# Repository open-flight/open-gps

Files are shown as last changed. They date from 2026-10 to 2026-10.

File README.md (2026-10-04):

# open-gps: Golf Shot Tracker

A handheld, open-source golf shot tracker built from SparkFun Qwiic parts. Turn the dial to pick a club, click at the ball, walk to where it landed, click again, and it shows the distance in yards. Every shot is saved to flash and can be exported over USB as GeoJSON or CSV, with start and landing coordinates for each shot.

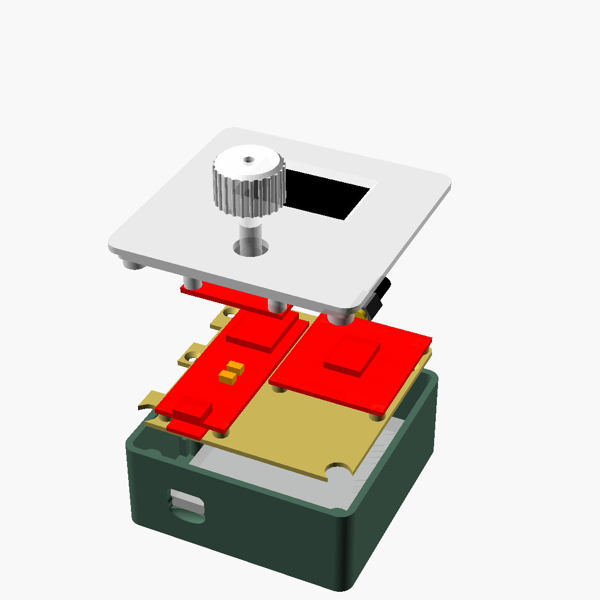
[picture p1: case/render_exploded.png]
Exploded view of the enclosure


> [!TIP]
> **🛒 [Get every part in one click: SparkFun wishlist](https://www.sparkfun.com/wishlist/shared/index/code/GlRlCXNElCsNx5QNRKp5i46RxsmUJz3x/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)**: all the electronics on one list, ready to add to your cart.
> <sub>This is a referral link, so buying through it supports the project at no extra cost to you. Prefer not to use it? Every part is listed in [Hardware](#hardware).</sub>

- **Firmware:** Arduino (ESP32-S3). A single-dial UI on a 128×64 OLED. Rounds survive resets and power loss.
- **Enclosure:** parametric OpenSCAD. It prints in PETG without supports and comes to 74.4 × 74.4 × 31.6 mm.
- **Host simulation:** the real firmware state machine runs on your computer against stubbed hardware, so most changes can be tested without the device.

| Path | What's there | More detail |
|---|---|---|
| `firmware/shot_tracker/` | Arduino sketch (`app.cpp` plus headers) | [firmware/README.md](firmware/README.md) |
| `firmware/test/` | Host simulation (`make -C firmware/test`) | [firmware/README.md](firmware/README.md) |
| `case/cad/shot_tracker_case.scad` | Enclosure source (single file, all parameters at the top) | [case/README.md](case/README.md) |
| `case/stl/` | Pre-exported printable parts | [case/README.md](case/README.md) |
| `tools/noop-ctags/` | Build workaround for Apple Silicon Macs without Rosetta | [Step 2](#2-build-the-firmware) |

---

## Hardware

> [!TIP]
> **[Add all the electronics to your cart from the SparkFun wishlist →](https://www.sparkfun.com/wishlist/shared/index/code/GlRlCXNElCsNx5QNRKp5i46RxsmUJz3x/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)**
> It covers the board, GPS, antenna, OLED, Twist, battery and Qwiic cables. You still need the screws, heat-set inserts and slide switch from [case/README.md](case/README.md#hardware). <sub>(Referral link.)</sub>

| Qty | Part | Notes |
|---|---|---|
| 1 | SparkFun Thing Plus ESP32-S3 | Main board: USB-C, LiPo charger, MAX17048 fuel gauge, one Qwiic port |
| 1 | SparkFun GPS Breakout NEO-M9N, SMA (Qwiic) | Edge-mount SMA jack |
| 1 | GPS/GNSS Magnetic Mount Antenna, 3 m (SMA) | Active antenna. The breakout powers it. |
| 1 | SparkFun Qwiic OLED 1.3" 128×64 | Monochrome |
| 1 | SparkFun Qwiic Twist RGB rotary encoder | The only control (turn, click, hold) |
| 1 | Lithium Ion Battery 2 Ah, JST-PH (SparkFun PRT-13855) | Measure yours. See [case/README.md](case/README.md#measure-before-you-print) |
| 1 | SparkFun Qwiic Cable Kit | |
| — | Screws, heat-set inserts, slide switch | Full list in [case/README.md](case/README.md#hardware) |

All parts share one I2C bus and the default addresses don't clash, so **no jumpers or address changes are needed**:

| Device | I2C address |
|---|---|
| MAX17048 fuel gauge (on the Thing Plus) | 0x36 |
| Qwiic OLED 1.3" | 0x3D |
| Qwiic Twist | 0x3F |
| NEO-M9N GPS | 0x42 |

---

## Quick start

These steps take you from a fresh clone to a flashed, working device. They're written so an agent can run them in order. Each step ends with a **Verify** check, so confirm it before moving on.

Requirements: macOS, Linux or Windows (WSL works for building, but flashing needs USB access); a USB-C **data** cable; and about 1.5 GB of disk space for the ESP32 toolchain.

### 0. Wire the parts (bench test before the case)

Don't have the parts yet? Use the [SparkFun wishlist](https://www.sparkfun.com/wishlist/shared/index/code/GlRlCXNElCsNx5QNRKp5i46RxsmUJz3x/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).

Daisy-chain the Qwiic cables. Electrically the order doesn't matter, because it's one bus:

```
Thing Plus ─ OLED ─ Twist ─ GPS
```

Inside the case, the GPS port facing the top wall has no room for a plug, so put the GPS **at the end of the chain**, using its bottom-facing port.

1. Screw the antenna onto the GPS SMA jack.
2. Optionally, plug the battery into the Thing Plus JST connector. USB power alone is enough for a bench test.
3. Plug the Thing Plus into the computer over USB-C.

### 1. Install the toolchain

Install `arduino-cli`:

| OS | Command |
|---|---|
| macOS | `brew install arduino-cli` |
| Linux | `curl -fsSL https://raw.githubusercontent.com/arduino/arduino-cli/master/install.sh \| sh` (installs to `./bin`; add it to `PATH`) |
| Windows | `winget install ArduinoSA.CLI` |

Then add the ESP32 core and the four libraries:

```bash
arduino-cli config init --overwrite   # only if you have no arduino-cli config yet; otherwise skip
arduino-cli config add board_manager.additional_urls https://espressif.github.io/arduino-esp32/package_esp32_index.json
arduino-cli core update-index
arduino-cli core install esp32:esp32
arduino-cli lib install "SparkFun u-blox GNSS v3" "SparkFun Qwiic OLED Arduino Library" \
  "SparkFun Qwiic Twist Arduino Library" "SparkFun MAX1704x Fuel Gauge Arduino Library"
```

**Verify:**

```bash
arduino-cli board listall | grep -i "ESP32-S3 Thing Plus"
# expected: SparkFun ESP32-S3 Thing Plus   esp32:esp32:sparkfun_esp32s3_thing_plus
arduino-cli lib list | grep -i sparkfun   # expect all four libraries
```

These versions are known to work: ESP32 core 3.3.12, u-blox GNSS v3 3.1.15, Qwiic OLED 1.0.15, Qwiic Twist 1.0.4 and MAX1704x 1.0.4.

### 2. Build the firmware

Run every command from the repository root. The board ID and options are:

```bash
FQBN="esp32:esp32:sparkfun_esp32s3_thing_plus:CDCOnBoot=cdc,PartitionScheme=default"
```

- `CDCOnBoot=cdc` is **required**. Without it, serial over the USB-C port is silent.
- `PartitionScheme=default` (4 MB flash, 1.5 MB SPIFFS) is where saved rounds live. Changing it **erases all rounds**.

```bash
arduino-cli compile -b "$FQBN" firmware/shot_tracker
```

**Apple Silicon Mac without Rosetta 2:** the build fails with `ctags: bad CPU type in executable`. That's because Arduino's `ctags` helper is Intel-only. You can either:

- install Rosetta with `softwareupdate --install-rosetta --agree-to-license`, or
- point the build at the stand-in `ctags` in this repo, which needs no system changes. It's safe because `shot_tracker.ino` has no functions, so `ctags` has nothing to do.

  ```bash
  arduino-cli compile -b "$FQBN" --build-property "tools.ctags.path=$PWD/tools/noop-ctags" firmware/shot_tracker
  ```

  Add the same `--build-property` to every compile and upload command below.

**Verify:** the output ends with `Sketch uses ~440000 bytes (33%) of program storage space`.

### 3. Find the port and flash

```bash
arduino-cli board list
```

| OS | Port looks like |
|---|---|
| macOS | `/dev/cu.usbmodem101` |
| Linux | `/dev/ttyACM0` (your user must be in the `dialout` group) |
| Windows | `COM3` |

```bash
PORT=/dev/cu.usbmodem101   # use the port from `board list`
arduino-cli compile --upload -p "$PORT" -b "$FQBN" firmware/shot_tracker
```

**Verify:** the output ends with `Hash of data verified.` and `Hard resetting via RTS pin...`

If no port appears or the upload fails:
1. Check that the EN slide switch is ON, if it's already wired.
2. Try a different USB-C cable. Charge-only cables don't show up as a port.
3. Put the board in upload mode by hand: **hold BOOT, tap RESET, release BOOT**, then upload again.
4. Press RESET afterwards to start the new firmware.

### 4. Check the hardware over serial

```bash
arduino-cli monitor -p "$PORT" -c baudrate=115200
```

Opening the monitor usually resets the board. If it doesn't, press RESET. You should see:

```
oled=1 twist=1 gps=1 fuel=1 fs=1
```

A `0` means that part wasn't found, so reseat its Qwiic cable. `fs=0` means the storage partition is missing; recheck `PartitionScheme=default`. The first boot formats storage, which leaves the screen blank for a few seconds. That's normal.

Type `gps` and press Enter:

```
present=1 fix=3 ok=1 siv=14 lat=... lon=... acc=1.20m unix=...
```

You want `fix=3` and `ok=1`. Indoors you'll usually see `fix=0 siv=0`. See [GPS won't get a fix](#gps-wont-get-a-fix).

For an agent without an interactive terminal, this sends commands and captures 8 seconds of output:

```bash
( (sleep 2; printf 'gps\nls\n'; sleep 5) | arduino-cli monitor -p "$PORT" -c baudrate=115200 --quiet > serial.log 2>&1 & P=$!; sleep 8; kill $P ); cat serial.log
```

### 5. Run the host simulation (no hardware needed)

```bash
make -C firmware/test
```

It needs `g++` or `clang++` (C++17). It plays a scripted round (drives, putts, hole-out, cancel, undo, a RESET mid-shot, a no-fix save, finishing, deleting a round, exporting and power-off), and it flags any text or graphics drawn off the 128×64 screen.

**Verify:** the last line is `0 failures`. AddressSanitizer hangs at startup on recent macOS, so on macOS the Makefile uses UBSan only. Linux uses both.

### 6. Print and assemble the case

The STLs in `case/stl/` are ready to print in PETG with no supports. Print orientation, slicer settings, the hardware list and the 8-step assembly order are all in **[case/README.md](case/README.md)**.

**Flash before you close the case.** Once the lid is on, the BOOT button is under the Twist.

To change the enclosure, edit the parameters at the top of `case/cad/shot_tracker_case.scad` and re-export:

```bash
# OpenSCAD 2021.01 is Intel-only on macOS; use the snapshot build (native on Apple Silicon):
brew install --cask openscad@snapshot        # macOS; Linux: your distro's openscad, or the AppImage
cd case
for p in shell lid plate knob plunger; do
  openscad --backend=manifold -D "part=\"$p\"" -o stl/$p.stl cad/shot_tracker_case.scad
done
```

Collision checks: each of these should print `Current top level object is empty`, or produce a zero-volume STL where parts only touch:

```bash
for c in chk_shell chk_lid chk_plate chk_shell_plate chk_shell_lid chk_lid_plate chk_plunger chk_plunger_lid; do
  echo "== $c"; openscad --backend=manifold -D "part=\"$c\"" -o /tmp/$c.stl cad/shot_tracker_case.scad 2>&1 | grep -E "empty|ERROR"
done
```

---

## Using it

There's one control, the dial: **turn** to choose, **click** to select or mark, and **hold** (0.7 s) for the menu.

1. **New round** starts on hole 1.
2. Turn to a club, then **click at the ball**. The device averages GPS for 2.5 s, so hold still.
3. Walk to the ball. The screen shows the live distance from where you hit.
4. **Click at the ball** again. The shot distance is shown in large digits and saved.
5. **Putter:** one click records the putt; there's no landing step.
6. **Hole out:** turn one step past Putter (the flag icon) and click.
7. **Saved rounds** on the home screen lists rounds, and you can delete one from there.

The header shows the hole and shot, a GPS pin with the satellite count (the pin blinks while searching), and a battery gauge with a bolt while charging. The dial's LED colour shows the state. The full controls, menu, LED colours and storage behaviour are in [firmware/README.md](firmware/README.md).

**Reset on the course:** press the RESET plunger on the lid, between the screen and the dial, or switch the EN slide switch off and on. The round resumes on the same hole and shot.

### Exporting rounds (USB serial, 115200 baud)

| Command | Output |
|---|---|
| `help` | Command list |
| `ls` | Rounds: id, shots, done/active, start time |
| `geojson <id>` | GeoJSON. Each shot is a start→landing line and each putt is a point. |
| `csv <id>` | CSV, one row per shot |
| `rm <id>` | Delete a round |
| `gps` | Current fix |

For a quick look, paste the `geojson` output into [geojson.io](https://geojson.io) and switch the base layer to satellite.

---

## Configuration

Firmware settings are in `firmware/shot_tracker/config.h`:

| Setting | Default | What it does |
|---|---|---|
| `CLUBS[]` | Driver … LW, Putter | The dial order. Names are up to 14 characters. The putter must match `PUTTER_NAME`. |
| `USE_YARDS` | `true` | `false` switches to metres |
| `GPS_MARK_WINDOW_MS` | 2500 | How long a mark averages GPS fixes |
| `GPS_MAX_GOOD_HACC_MM` | 8000 | Fixes less accurate than this are ignored while marking |
| `LONG_PRESS_MS` | 700 | How long to hold for the menu |
| `RESULT_SHOW_MS` | 4000 | How long the shot distance stays on screen |

Enclosure settings are at the top of `case/cad/shot_tracker_case.scad`. The ones you're most likely to change:
- `batt`: the battery pocket, currently 55 × 64 × 6.4. If you change its length, change `plate_region_h` by the same amount.
- `rst_recess`: how far the RESET plunger stands out from the lid. Negative means it sticks out.
- `sw_*`: the slide switch size.
- The clearances `clr` and `lip_clr`.

---

## Troubleshooting

### GPS won't get a fix
- **Indoors:** `siv=0` or only a few weak satellites is normal. Run the 3 m antenna cable outside or onto a windowsill.
- **Interference:** keep the antenna at least 1 m from the laptop, the ESP32 board and the USB cable. All of them radiate noise near the GPS band.
- **Ground plane:** the magnetic puck works best on a steel surface, such as a baking tray, outdoors.
- **First fix (cold start):** this can take 1–3 minutes under open sky. Later fixes are much faster.
- **Antenna check:** the NEO-M9N reports antenna status over UBX `MON-HW`. `aStatus=2` means OK and `aPower=1` means powered. A short sketch that prints `getHWstatus()` and `getNAVSAT()` from the u-blox library, using signal strength (C/N0) and the jamming indicator, quickly separates antenna, cable and interference problems.

### Build and flash
| Symptom | Fix |
|---|---|
| `ctags: bad CPU type in executable` | Apple Silicon without Rosetta. Use `--build-property tools.ctags.path=$PWD/tools/noop-ctags` (Step 2). |
| No serial output at all | `CDCOnBoot=cdc` is missing from the FQBN |
| No port appears | Use a data cable, turn EN ON, or use BOOT + RESET (Step 3) |
| `fs=0` at boot | Wrong partition scheme. Use `PartitionScheme=default`. |
| `make -C firmware/test` hangs on macOS | Older Makefile using ASan. The current Makefile uses UBSan only on macOS. |

### Saved rounds and reflashing
- Normal uploads **keep** saved rounds; they live in a separate flash partition.
- These **erase all rounds**, so export first:
  - *Erase All Flash Before Sketch Upload*
  - changing the partition scheme
  - `esptool erase_flash`
- Bumping `ROUND_VERSION` in `model.h` makes older rounds unreadable.

---

## Power notes

- **Power off** (in the menu) saves the round, cuts the Qwiic rail (GPIO45) and deep-sleeps. Press RESET to wake it.
- The **EN slide switch** is the hard off. The battery still charges over USB while it's off.
- Recommended board mods (cut-trace jumpers on the Thing Plus):
  - **JP2:** the Qwiic rail's default pull-up. Cutting it stops about 330 µA of drain while the device is off.
  - **JP1:** the power LED. Cutting it saves about 1 mA while running.
- Charging runs at about 213 mA, so a full 2 Ah charge takes around 10 hours.

---

## Roadmap (not in v0.1)

- Penalty strokes and provisional balls
- Choosing which clubs to carry
- Pin and green positions, and a course-overlay viewer (the GeoJSON properties are designed for this)
- Auto sleep between holes
- BLE sync to a phone
- An internal patch antenna, and a belt or cart clip

## Contributing

1. Run `make -C firmware/test` before and after firmware changes; it must end in `0 failures`. Add a check to `firmware/test/sim.cpp` for new behaviour.
2. For case changes, run the collision checks in Step 6, re-export the affected STLs, and update `case/README.md` if dimensions or assembly change.
3. Keep screen text and graphics within 128×64. The simulation flags anything that runs off the screen.

## License

Copyright (C) 2026 Coleman Rollins and open-gps contributors.

open-gps is licensed under the **GNU Affero General Public License v3.0**; see [LICENSE](LICENSE). That covers the firmware, the enclosure CAD and STLs, and the documentation. You can use, modify and share it, but if you distribute a modified version, or run one as a network service, you must release your changes under the same license.

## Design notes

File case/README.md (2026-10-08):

# Golf Shot Tracker – Handheld Enclosure (v0.1)

A parametric OpenSCAD enclosure for the SparkFun plug-and-play shot tracker. It holds these parts:

- SparkFun Thing Plus ESP32-S3
- SparkFun GPS Breakout NEO-M9N, SMA (Qwiic)
- SparkFun Qwiic OLED 1.3" 128x64
- SparkFun Qwiic Twist RGB Rotary Encoder
- Lithium Ion Battery 2Ah
- GPS/GNSS Magnetic Mount Antenna 3m (SMA)
- SparkFun Qwiic Cable Kit

Board outlines, mounting holes and connector positions come from SparkFun's own Eagle and KiCad source files on GitHub. Only the parts listed under "Measure before you print" were estimated.

## Size

The case is 74.4 x 74.4 x 31.6 mm (W x H x D). The GPS antenna plugs into an SMA port in the top wall, and the antenna and its cable stay outside the case.

## Layout

Viewed from the front:

- **Top wall:** the SMA antenna port. This is the GPS board's own edge-mount SMA jack, sitting 0.6 mm behind the wall. An 11 mm opening lets the plug's coupling nut reach the thread. To its left are a zip-tie anchor (to strain-relieve the antenna cable) and a lanyard lug. To its right, a small bulge holds a 5 mm pocket behind the GPS's top-edge Qwiic port, so a plug fits there.
- **Front:** the OLED window with the Twist dial below it, and the **RESET button** between them. A printed plunger, standing 1 mm proud of the lid, presses the Thing Plus RESET button, which wakes the device from firmware power-off.
- **Left side:** the **EN slide switch**, the hard power-off. It pulls the Thing Plus EN pin to GND, which disables the main 3.3 V regulator. Charging still works with it off.
- **Bottom end:** USB-C (charging and programming) and a microSD slot, both on the Thing Plus.
- **Inside, stacked from the back:** the battery sits on the floor. An internal plate sits above it and carries the Thing Plus (left) and the GPS (right, rotated so its SMA faces the top wall).
- **Lid:** the OLED and the Twist screw onto bosses on the lid.
- **Closing:** the lid has two tongues that hook under the top wall. It swings down and is held by two M3 screws from the back.

## Files

- `cad/shot_tracker_case.scad`: single source file. Set `part` to `shell`, `lid`, `plate`, `knob`, `plunger`, `assembly` or `exploded`.
- `stl/`: pre-exported parts in print orientation.

To re-export a part:
```
openscad -D 'part="shell"' -o shell.stl cad/shot_tracker_case.scad
```
Collision-check targets (`chk_shell`, `chk_lid`, `chk_plate`, …) intersect each part with the ghost components. They should come back empty or zero-volume.

## Hardware

| Qty | Item | Where |
|---|---|---|
| 2 | M3 heat-set insert, 4.0 mm hole, ≤5.8 mm long | lid bottom corners |
| 2 | M3 x 25 socket head | back → lid |
| 6 | M2.5 x 5 pan head (self-tapping into PETG) | Thing Plus (2), GPS (4) → plate. **Don't use longer than 5 mm.** A 6 mm screw pokes through the plate toward the battery. |
| 3 | M2.5 x 6 flat head | plate → shell pillars |
| 4 | M2.5 x 8 pan head | Twist → lid |
| 4 | M2.5 x 4 pan head | OLED → lid (longer screws will dimple the lid face) |
| 1 | Mini SPDT slide switch, SS12D00G3-style (8.7 x 3.6 x 3.6 mm body, 3-pin, 2.54 mm pitch) | left wall, wired EN ↔ GND |
| 2 | ~6 cm of 28–30 AWG wire | switch to the Thing Plus EN and GND pins |
| 1 | Small square of 1 mm foam tape | behind the battery (optional anti-rattle) |

## Printing (Bambu X2D, PETG)

- 0.4 mm nozzle, 0.2 mm layers, 3–4 walls, 20% gyroid.
- No supports needed on any part.
- **Shell:** print back-down.
- **Lid:** print face-down. A textured PEI plate gives a nice front finish.
- **Plate:** print flat.
- **Knob:** print upright. Use clear or translucent PETG so the encoder's RGB light shows through the centre light pipe.
- **Plunger:** print upright, tip down. Use 0.12 mm layers for a clean 2.1 mm shaft.

## Assembly order

1. Press the 2 M3 inserts into the lid corner bosses. Drop the RESET plunger into its guide tube from inside the lid. Its collar keeps it from falling out the front.
2. Screw the OLED (face down, glass against the lid) and the Twist (encoder through the round hole) to the lid. Plug in Qwiic cables. OLED → Twist is a short hop.
3. Solder the slide switch: the centre pin to the Thing Plus **EN** pin and one outer pin to **GND**. Slide = off pulls EN low. Hold the switch against the left wall with the actuator through the slot and fix it with hot glue (there's no cradle; the plate has a notch so it drops in past the switch).
4. Put the battery in the shell. The lead exits toward the left side.
5. Screw the Thing Plus and the GPS to the plate, then drop the plate in over the battery. Route the battery lead up through the left notch into the Thing Plus JST. Screw the plate down (3x M2.5 flat head).
6. Connect Qwiic: Thing Plus → GPS → OLED → Twist. Both GPS Qwiic ports are usable. The one facing the top wall plugs into the pocket beside the SMA port.
7. Hook the lid's top tongues under the top wall, swing the bottom down, and fit the 2 M3 x 25 screws from the back.
8. Screw the antenna onto the SMA port. Zip-tie the cable to the anchor next to the port so tugs don't load the GPS board's edge connector.

## Measure before you print

These values were estimated or conflict between sources. Every one is a single parameter at the top of the `.scad` file.

- **`batt`:** SparkFun and DigiKey list 61 x 53.3 x 6.4 mm, but some resellers list 68.8 x 49.2 x 5.6 mm. The default pocket is 55 x 64 (2 mm longer than the listed cell, which measured tight in practice). If yours is the longer cell, it won't fit without reworking the layout.
- **`oled_glass_t`:** glass plus adhesive thickness (default 1.6). This sets the OLED boss height.
- **`enc_body` / `enc_hole_d`:** encoder body 12.4 x 13.4 x 7.8 mm, from a third-party model of COM-15141. The lid hole clears an M9 bushing.
- **`sw_body` / `sw_slot`:** the slide switch body and actuator slot. Measure your switch.
- **`sma_edge_gap` / `sma_port_d`:** the gap between the GPS board edge and the top wall, and the port opening size. If the plug won't thread fully, reduce the gap or enlarge the opening.

## Known limitations / next steps

- **External antenna.** The antenna rides outside the case on its 3 m cable. A small active patch antenna could later go inside the case, or in a snap-on cap over the port.
- **Board mods:** cut JP2 on the Thing Plus so firmware power-off doesn't fight the Qwiic rail's 10k pull-up. Details are in the firmware README.
- **Slow charging.** The Thing Plus charger runs at ~213 mA, so a full 2 Ah charge takes roughly 10 hours. Fine overnight, slow for a top-up.
- **No weather sealing** (per v0.1 scope).
- **No belt or cart clip yet.** The back is flat, so a clip or mount plate can be added later.

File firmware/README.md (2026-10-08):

# Shot Tracker Firmware (v0.1)

Arduino firmware for the SparkFun Thing Plus ESP32-S3 with the NEO-M9N GPS, the Qwiic OLED 1.3" and the Qwiic Twist.

## Controls

There's one control, the dial:

- **Turn** to pick a club or move through menus.
- **Click** to select or to mark a position.
- **Hold** (0.7 s) to open the menu. Holding again closes it.

## Playing a round

1. From the home screen, choose **New round**. The round starts on hole 1.
2. **Pick a club.** Turn the dial and the club name shows on screen.
3. **Click at the ball.** The device averages GPS for 2.5 s ("Hold still"). That marks the start of the shot.
4. **Walk to the ball.** The screen shows the live distance from the start.
5. **Click at the ball again.** The landing point is marked and the shot distance is shown for 4 s.
6. **Putts:** select *Putter* and one click records the shot. There's no landing step. The dial stays on the putter for the next putt.
7. **Finish the hole:** turn one click past *Putter* to **Hole out** and click. That advances to the next hole. Holing out on 18 asks whether to finish the round.

**Dial LED colours**

| Colour | Meaning |
|---|---|
| Green | Ready |
| Blue | Shot in flight |
| White | Marking a position |
| Amber | No GPS fix |
| Purple | In a menu |

**Menu** (hold the dial during a round):

- Back
- Next hole
- Go to hole…
- Cancel this shot / Undo last shot (asks to confirm)
- Scorecard
- GPS status
- End round (asks to confirm)
- Power off

**Saved rounds** (home screen) lists the newest 9 rounds as `#id date shots`; `*` marks a round that was never finished. Click a round to delete it (asks to confirm, defaults to No). Older rounds appear as newer ones are deleted, or remove them over USB with `rm <id>`.

**If there's no GPS fix when you mark:** you get a choice of *Try again*, *Save without GPS* or *Cancel*. Save without GPS keeps the stroke count correct, but that shot has no distance.

## Storage and resume

- **Where rounds live:** in LittleFS on the internal flash. The round is rewritten after every change, using a temp file and a swap, so power loss can't corrupt it.
- **Resume:** a RESET, a dead battery or the EN switch mid-round all come back to the same hole and the same shot. That includes a shot that's still in flight.
- **Capacity:** 250 shots per round. The 1.5 MB partition holds hundreds of rounds.

## Exporting rounds (USB serial, 115200)

| Command | Output |
|---|---|
| `ls` | List rounds (id, shots, done/active) |
| `geojson <id>` | Export as GeoJSON. Each shot is a start→landing line and each putt is a point. Properties include club, distance and accuracy. |
| `csv <id>` | Export as CSV, one row per shot |
| `rm <id>` | Delete a round |
| `gps` | Current fix |

To replay a round on a satellite map, save the `geojson` or `csv` output to a file and open it in the round replay viewer: open [`tools/replay/index.html`](../tools/replay/index.html) in a browser (straight from disk is fine) and drop the file on it. It walks through the round shot by shot with a scorecard and per-club stats. See [`tools/replay/README.md`](../tools/replay/README.md). The CSV is the complete record: the GeoJSON leaves out shots saved without GPS.

## Power

The *Power off* menu item:

1. Saves the round.
2. Cuts the Qwiic rail with GPIO45, which switches off the GPS, OLED and Twist.
3. Holds that pin low.
4. Deep-sleeps with no wake source.

To wake it, press the **RESET** button on the lid. The **EN slide switch** on the side is the hard off. It disables the main 3.3 V regulator, and the battery still charges over USB while it's off.

**Recommended board mods** (cut-trace jumpers on the Thing Plus):

- **JP2:** the rail's default pull-up. Cut it so the Qwiic rail defaults *off*. Otherwise GPIO45 fights a 10k pull-up (about 330 µA) the whole time the device is "off". The firmware drives the pin high at boot either way, so nothing else changes.
- **JP1:** the red power LED. It's optional to cut, and it saves roughly 1 mA+ while running.

## Building

**Arduino IDE 2 or arduino-cli, with the Espressif ESP32 core:**

- **Board:** *SparkFun ESP32-S3 Thing Plus* in core 3.x. On older 2.0.x cores, use *ESP32S3 Dev Module* with 4 MB flash.
- **USB CDC On Boot:** *Enabled*. This is needed for serial over the USB-C port.
- **Partition scheme:** *Default 4MB with spiffs*. LittleFS uses the spiffs partition.

**Libraries** (Library Manager):

- SparkFun u-blox GNSS v3
- SparkFun Qwiic OLED Arduino Library
- SparkFun Qwiic Twist Arduino Library
- SparkFun MAX1704x Fuel Gauge Arduino Library

```
arduino-cli compile -b "esp32:esp32:sparkfun_esp32s3_thing_plus:CDCOnBoot=cdc,PartitionScheme=default" firmware/shot_tracker
```

## Flashing

Do the first flash **before you close the case**. The BOOT button you may need for recovery sits under the Twist once the lid is on.

### One-time setup

**Arduino IDE 2:**

1. Go to *Settings → Additional boards manager URLs* and add
   `https://espressif.github.io/arduino-esp32/package_esp32_index.json`
2. In *Boards Manager*, install **esp32 by Espressif Systems**.
3. In *Library Manager*, install the four libraries listed under Building.

**arduino-cli:**
```
arduino-cli config add board_manager.additional_urls https://espressif.github.io/arduino-esp32/package_esp32_index.json
arduino-cli core update-index
arduino-cli core install esp32:esp32
arduino-cli lib install "SparkFun u-blox GNSS v3" "SparkFun Qwiic OLED Arduino Library" \
  "SparkFun Qwiic Twist Arduino Library" "SparkFun MAX1704x Fuel Gauge Arduino Library"
```

### Upload

1. Plug the Thing Plus into your computer over USB-C. Use a data cable; some charge-only cables won't show up.
2. Pick the port:

   | OS | Port name |
   |---|---|
   | macOS | `/dev/cu.usbmodem…` |
   | Linux | `/dev/ttyACM0` (your user needs to be in the `dialout` group) |
   | Windows | `COMx` |

3. **Arduino IDE:** open `firmware/shot_tracker/shot_tracker.ino`.
   - Set *Tools → Board* to **SparkFun ESP32-S3 Thing Plus**. On older 2.0.x cores, use *ESP32S3 Dev Module* with Flash Size = 4MB.
   - Set *USB CDC On Boot* to **Enabled**.
   - Set *Partition Scheme* to **Default 4MB with spiffs**.
   - Then click **Upload**.
4. **arduino-cli:**
   ```
   arduino-cli board listall | grep -i "thing plus"      # confirm the board ID on your core version
   arduino-cli compile --upload -p /dev/cu.usbmodem101 \
     -b "esp32:esp32:sparkfun_esp32s3_thing_plus:CDCOnBoot=cdc,PartitionScheme=default" \
     firmware/shot_tracker
   ```
   On Apple Silicon without Rosetta, add `--build-property tools.ctags.path=$PWD/tools/noop-ctags` (see the top-level README). Keep `CDCOnBoot=cdc`.
5. Open a serial monitor at 115200. On boot it prints `oled=1 twist=1 gps=1 fuel=1 fs=1`. A `0` means that part wasn't found; check its Qwiic cable. Type `help` for the export commands.

The first boot formats the storage partition, which takes a few seconds with a blank screen. That's normal.

### If the upload fails or the port disappears

Normally the ESP32-S3 resets itself into upload mode over USB. If the firmware crashes early, or the port never appears:

1. Open the case.
2. **Hold BOOT, tap RESET, then release BOOT.** The board is now in upload mode and a port should appear. It may have a different name than usual.
3. Upload again.
4. Press RESET afterwards to run the new firmware. The board doesn't always leave upload mode on its own.

**The EN slide switch has to be ON.** With it off the board has no 3.3 V and won't show up over USB, even though the battery is still charging.

### Saved rounds and reflashing

- **Rounds survive normal uploads.** They live in a separate flash partition.
- **These wipe every saved round**, so export first (`ls`, then `geojson <id>`):
  - turning on *Erase All Flash Before Sketch Upload*
  - changing the *Partition Scheme*
  - running `esptool erase_flash`
- **Changing the storage format** (bumping `ROUND_VERSION` in `model.h`) makes older rounds unreadable. They stay on flash but won't load.

**Code layout:**

| File | Contents |
|---|---|
| `config.h` | Clubs, units, timings, GPS averaging |
| `model.h` | Round/shot structs and distance maths |
| `storage.h` | LittleFS persistence and GeoJSON/CSV export |
| `gps.h` | GNSS wrapper and averaged marking |
| `input.h` | Dial click/long-press handling |
| `ui.h` | OLED helpers |
| `app.cpp` | State machine, screens and serial commands |

**Host simulation:** `make -C firmware/test` builds the real `app.cpp` against stubbed hardware with sanitizers. It plays a scripted round: drives, putts, hole-out, cancel, undo, a RESET mid-shot, a no-fix save, going to hole 18, finishing, exporting and power-off. It asserts the results and checks that no text or graphics run off the 128×64 display.

## Not in v0.1

- Penalty strokes and provisional balls.
- Picking which club list to carry.
- Pin or green positions.
- Auto sleep between holes.
- BLE sync to a phone.

The GeoJSON properties are meant to be the starting point for the course-overlay viewer.

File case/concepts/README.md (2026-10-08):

# Enclosure concepts (v0.2 exploration)

This folder has two new enclosure concepts and a mount system they share. Both are designed for the same two jobs:

1. **In the hand while walking.** One hand holds it, the thumb is on the dial, and you glance at the screen.
2. **Mounted** on a push-cart or riding-cart bar, or on a golf-bag strap, where the screen has to be readable at a glance.

These are **concept-level massing models**, not print-ready parts. Each one has the real components ghosted inside, at the SparkFun sizes copied from `../cad/shot_tracker_case.scad`. Every model passes two automated fit checks: no part intersects the shell, and nothing sticks outside the outer skin. The dial, screen, USB-C, microSD, SMA, RESET and EN all have openings. Screw bosses, lid retention, ribs and tolerances are only roughed in.

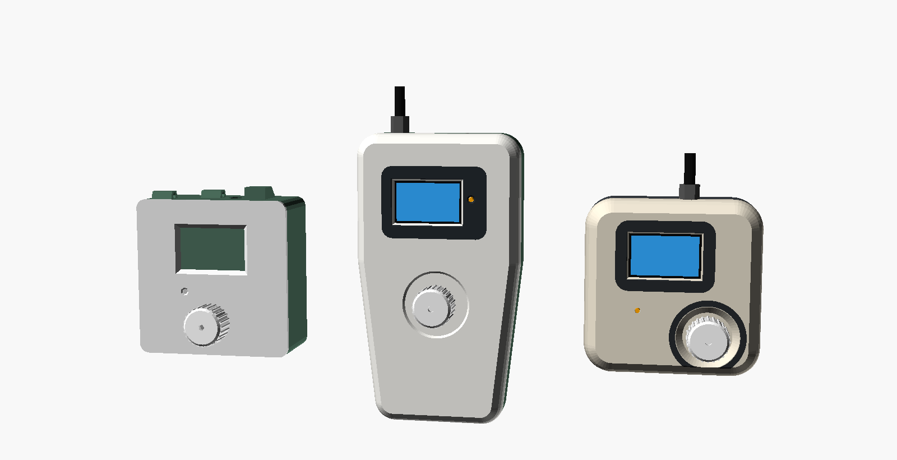
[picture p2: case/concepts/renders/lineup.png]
lineup

*To scale, left to right: v0.1 (74.4 x 78 x 31.6), **A Grip** (78.6 x 138.3 x 22.8), **B Stone** (79.4 x 80.4 x 29.6).*

---

## Concept A: "Grip"

**Pitch:** a slim handheld about the size of a SkyCaddie. The battery sits in the handle and the dial sits right where your thumb rests.

| Front | Back (palm pad + mount socket) | Section | Lid off |
|---|---|---|---|---|
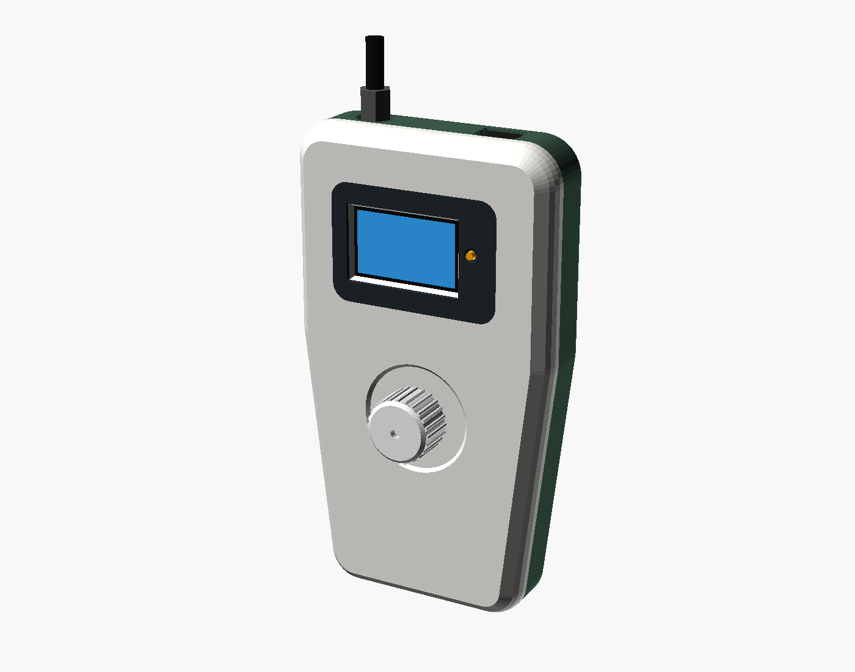
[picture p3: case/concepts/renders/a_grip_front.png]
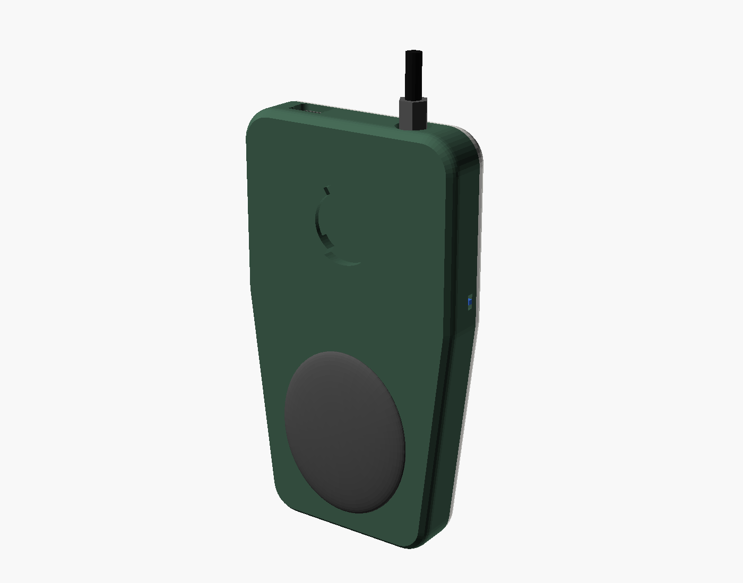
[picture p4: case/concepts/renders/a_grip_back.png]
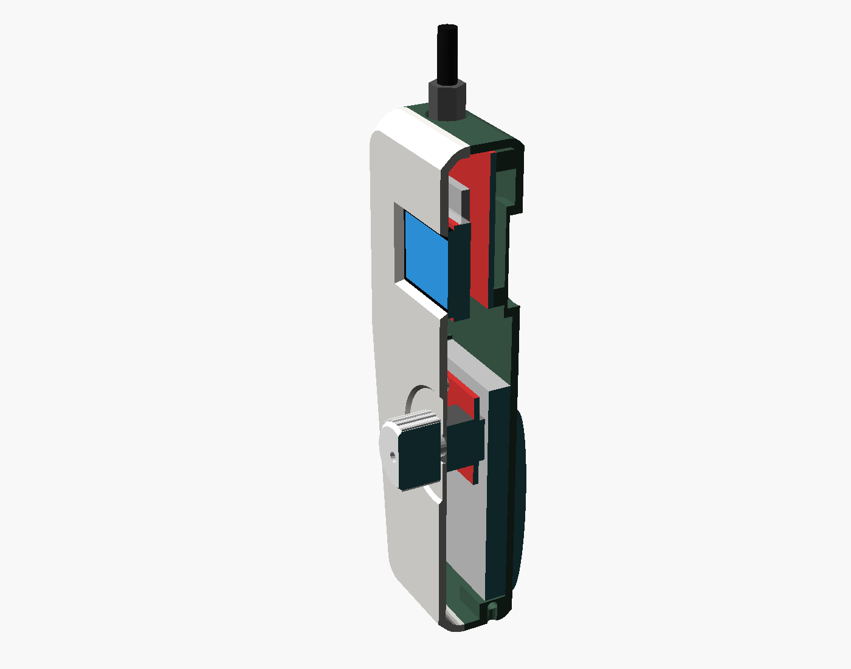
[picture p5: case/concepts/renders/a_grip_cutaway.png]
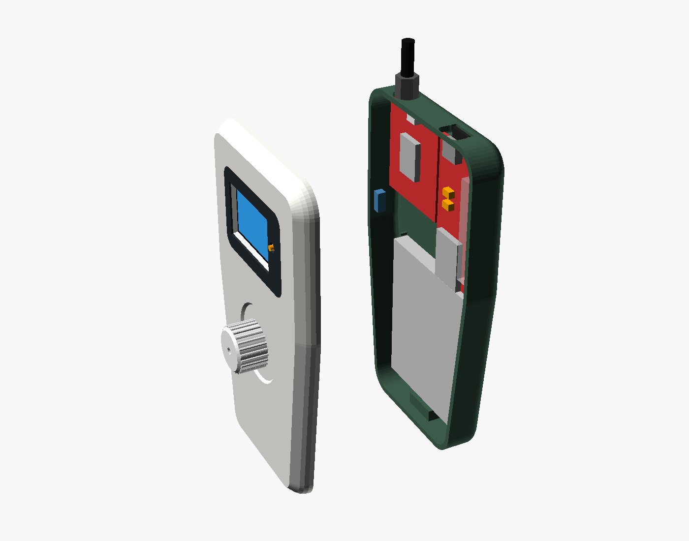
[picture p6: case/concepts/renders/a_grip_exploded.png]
|  |  |  |  |

**Outer size:** 78.6 wide at the head, tapering to 62.6 at the bottom of the handle. It is 138.3 long and 22.8 deep, or 26.3 deep over the palm pad. The envelope is about 223 cm³.

**How it's held:** like a TV remote. Your fingers wrap the narrow handle and your thumb lands on the dial, 58 mm from the bottom end, in a shallow 32 mm thumb pocket. The screen sits above your hand, so the thumb never covers it. The battery is the heaviest part and it sits in the palm, so the device doesn't feel top-heavy. A separate TPU palm pad fills the hollow of the palm. Wrist-strap holes are in the bottom end.

**How it's mounted:** the TwistLock socket is flush in the back of the head, behind the screen. On a cart bar, the handle hangs below the clamp. I checked it clears the clamp and a 25.4 mm bar at 55° of tilt (`part="chk_cart"`).

**Internal layout.** The boards sit side by side instead of stacked, so the inside is only 18.4 mm deep:
- **Handle:** the 55 x 64 x 6.4 pouch lies flat on the floor. The Twist hangs from the lid bosses directly above it. Its encoder pins clear the pouch by 0.4 mm, plus the 0.6 mm swell allowance.
- **Head:** the GPS (left, SMA pointing up) and the Thing Plus (right) sit side by side on 5.5 mm floor bosses. The Thing Plus is rotated 180° so its USB-C faces the top end. There's no internal plate. The OLED sits over both boards with its glass against the lid.
- A 3.5 mm channel between the two zones carries the battery lead and the Qwiic cables.

**Where everything is:**

| Item | Location |
|---|---|
| USB-C and microSD | Top end, right |
| SMA | Top end, left |
| RESET plunger | Right of the screen. That's where the Thing Plus RESET lands after the rotation; the screen is nudged 4 mm left to make room. |
| EN switch | Left side, below the GPS |

**Tradeoffs:**
- **Printability.** No supports are needed. The back shell prints back-down: the back is flat, and the edges start with a 45° lead-in before the radius. The lid prints face-down, and the dark screen panel can be the first layers from the X2D's second nozzle (or the lid can be single-colour). The thumb pocket floor is a 30 mm bridge, 1 mm deep. The socket lip sits on the bed and its chamber ceiling is a 25.6 mm bridge. The palm pad prints flat side down.
- **Size.** Thinnest of the three, but 138 mm long. It fits a jacket pocket, not a trouser pocket.
- **Comfort.** The best of the three for one-handed use: narrow grip, a natural thumb position, and the screen is never under your thumb.
- **Cost and complexity.** About the same as v0.1. It loses the internal plate and gains the palm pad. The new layout is the risk (see below).

**Unproven:**
- **Thing Plus plug keep-out.** I assumed the JST battery and Qwiic plugs need a 7 mm side clearance along the board edge that now faces the right wall (local y 8–50). Verify the real positions. If the JST sits elsewhere, the head may need re-balancing.
- **GPS Qwiic port.** The design uses the GPS's other Qwiic port, not J4 on the SMA edge, so it doesn't need v0.1's pocket bulge. Confirm that port is reachable.
- **Qwiic cable lengths.** The cables now run between the zones (Thing Plus → GPS → OLED → Twist). Check them against the cable kit lengths.
- **Palm pad attachment.** It would attach with VHB tape plus two locating pins. That isn't modelled.

---

## Concept B: "Stone"

**Pitch:** v0.1's proven internal stack in a soft, compact palm stone. The dial moves to the lower right for the thumb, which also makes the case thinner.

| Front | Back (socket + strap holes) | Section through the dial | Exploded |
|---|---|---|---|
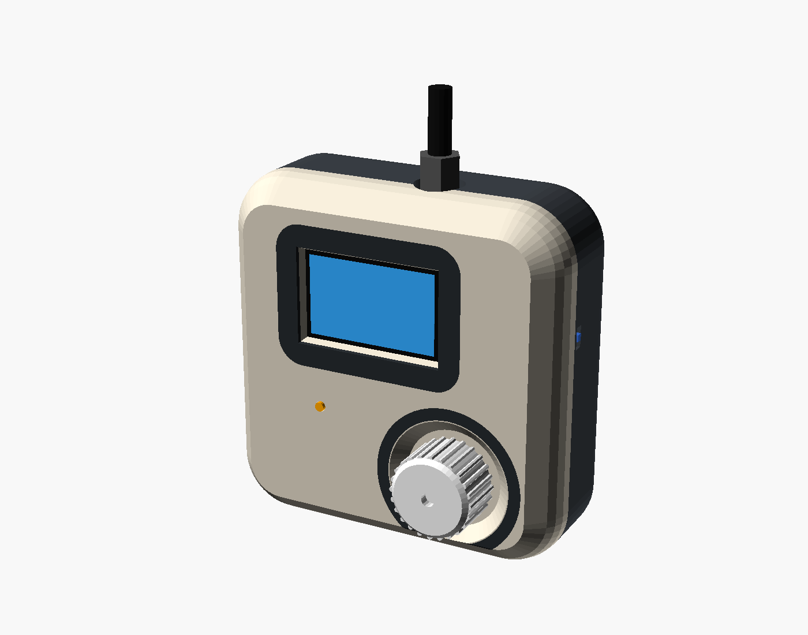
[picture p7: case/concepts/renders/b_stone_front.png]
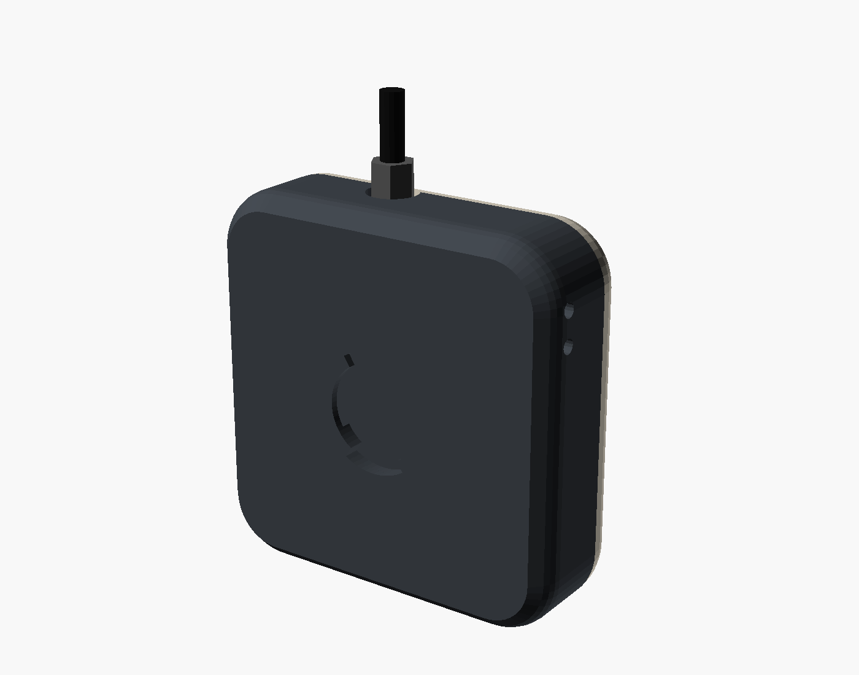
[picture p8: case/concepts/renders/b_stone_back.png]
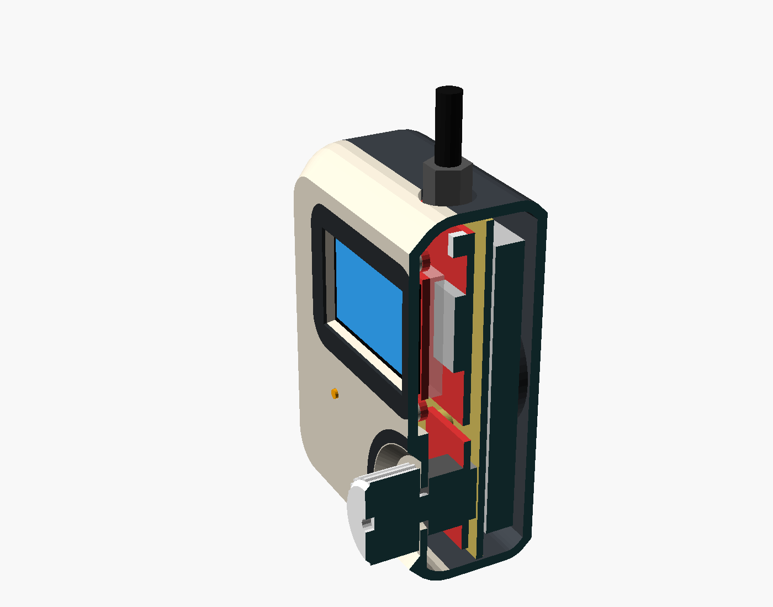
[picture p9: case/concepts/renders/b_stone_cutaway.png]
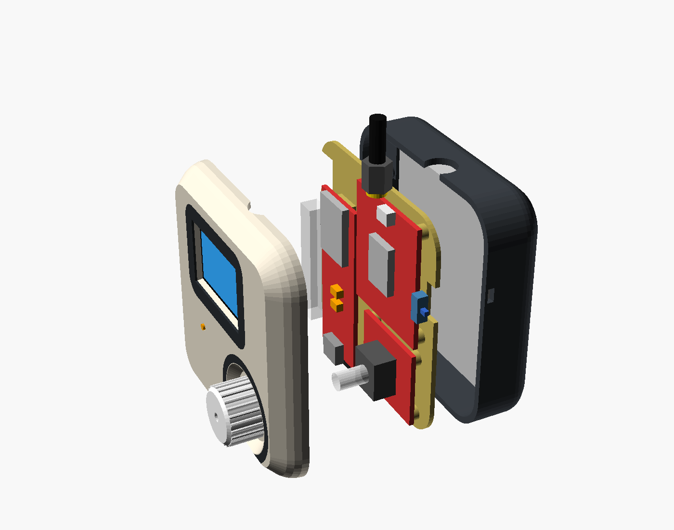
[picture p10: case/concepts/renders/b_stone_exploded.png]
|  |  |  |  |

**Outer size:** 79.4 x 80.4 x 29.6 mm. The envelope is about 177 cm³, about the same as v0.1 but 2 mm thinner, with no sharp edges and nothing sticking out of the back.

**How it's held:** cupped in the palm like a stopwatch. The dial sits in the lower-right corner, about 22 mm from the right edge and 19 mm from the bottom, so a right thumb rests on it without shifting your grip. The knob sits in a 3 mm deep dial cup, so it's lower and protected in a bag. Wrist-strap holes are on the left side.

**How it's mounted:** the TwistLock socket is in the centre of the back. The device is compact and centred on the clamp, so it's the tidiest of the two on a cart.

**Internal layout.** Battery on the floor, then the chassis plate, then the Thing Plus and GPS on the plate, then the OLED under the lid, as in v0.1. Three changes:
- **The Twist moves off the boards** into the free plate corner beside the GPS, on 2 mm plate standoffs. In v0.1 it stacked on the Thing Plus, which set the depth. Now the encoder sits just under the dial-cup floor.
- **The GPS sits 2.2 mm off the top wall** instead of 0.6, so the top-right corner can have an 11 mm radius.
- **The pouch is raised 2.6 mm** onto the socket boss. That's the cost of a flush mount socket. Without the socket, B would be 27 mm deep.

**Where everything is:**

| Item | Location |
|---|---|
| USB-C and microSD | Bottom end (as v0.1) |
| SMA | Top end |
| RESET | Below the screen, lower left |
| EN switch | Right side, beside the GPS |

**Tradeoffs:**
- **Printability.** Same rules as A, and no supports are needed. The dial cup has a 45° wall so it prints face-down. I dropped the crowned face I first tried, because a crowned face won't sit flat for a face-down print.
- **Size.** About v0.1's volume. It's wider and taller than v0.1 (79 x 80 vs 74 x 78) but thinner.
- **Comfort.** Fine in the hand and nicer than v0.1 (rounded everywhere, thumb-placed dial). It isn't a true grip, though: your fingers hold the edges.
- **Cost and complexity.** The lowest risk of the two, because the stack and the plate are v0.1's. It's right-thumb biased and can't be mirrored, because the Thing Plus occupies the bottom-left corner.

**Unproven:**
- **SMA reach.** With the 2.2 mm gap, the jack's thread starts 0.5 mm inside the inner wall (in v0.1 it started 1.1 mm outside). The plug nut has to reach about 1.7 mm into the 11 mm port. Check with the real antenna plug. If it doesn't reach, thin the wall locally or widen the port.
- **Knob grip.** The knob gives 2–5 mm of finger room in the cup and stands about 9 mm proud, so you turn it from the top and side. A test print of the lid will tell whether that's comfortable.
- **Encoder shaft length.** I assumed 10 mm of shaft above the encoder body, as v0.1 modelled. The knob then engages 8 mm.

---

## Concept B2: "Stone, layered"

You picked B. B2 is the iteration: a **smaller footprint, bought with depth**, and a softer side section. `concept_b_stone.scad` is unchanged, for comparison.

**B2 is now print-ready.** See [Printing B2](#printing-b2) below. Making it printable changed four things in the concept described here:
- **Dial cup removed.** The Twist moved up 2 mm so its encoder bears on the lid, as in v0.1.
- **Lean reduced from 6 to 4.9 mm,** so the bottom corners stay under 45°.
- **Wrist-strap passage moved** to the bottom end.
- **Lid retention added:** tabs inside the shell and three side screws.

The text below is updated to match.

| Front | Side (the lean) | Back | Section through the RESET plunger | Exploded layers |
|---|---|---|---|---|
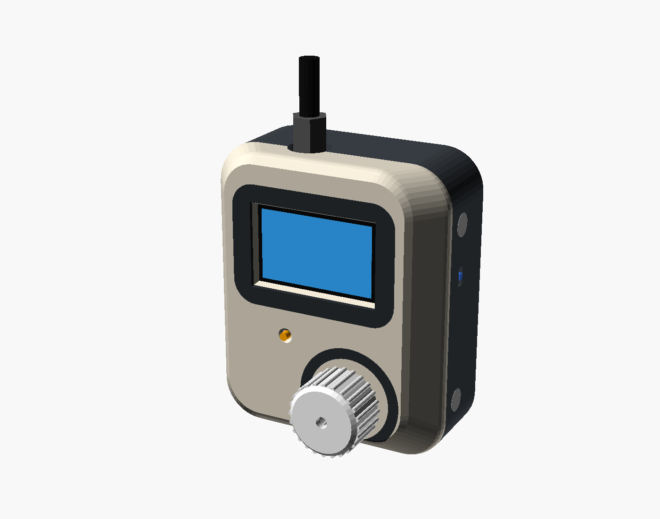
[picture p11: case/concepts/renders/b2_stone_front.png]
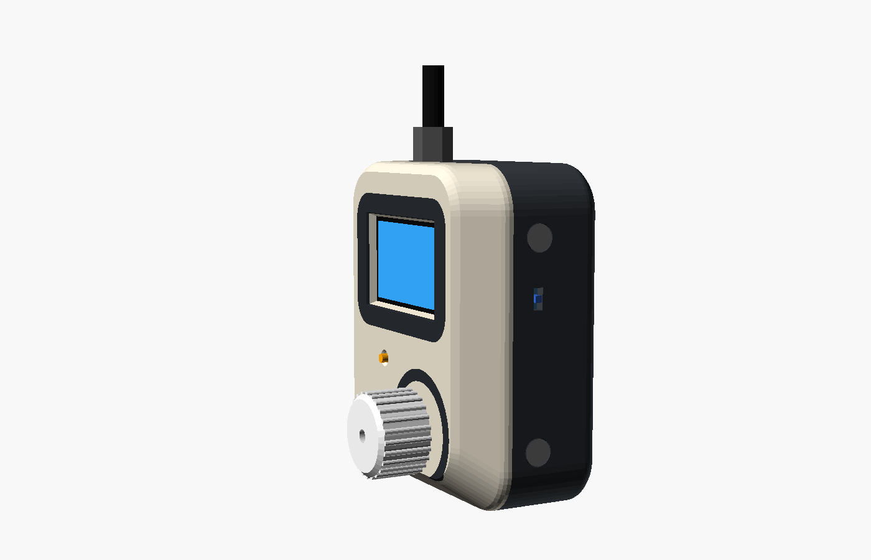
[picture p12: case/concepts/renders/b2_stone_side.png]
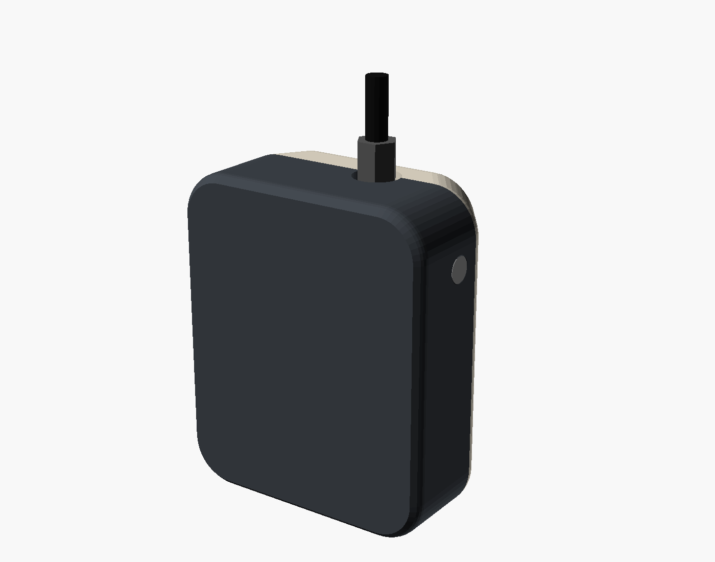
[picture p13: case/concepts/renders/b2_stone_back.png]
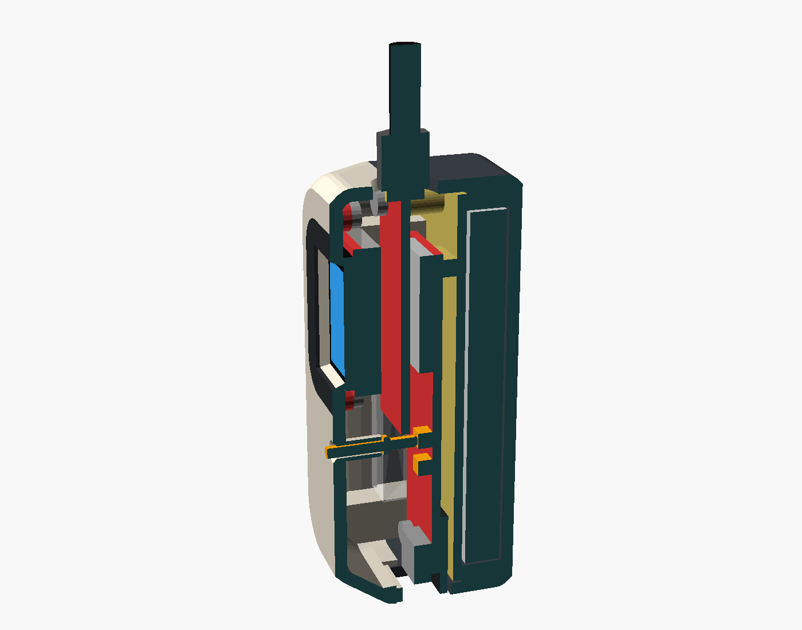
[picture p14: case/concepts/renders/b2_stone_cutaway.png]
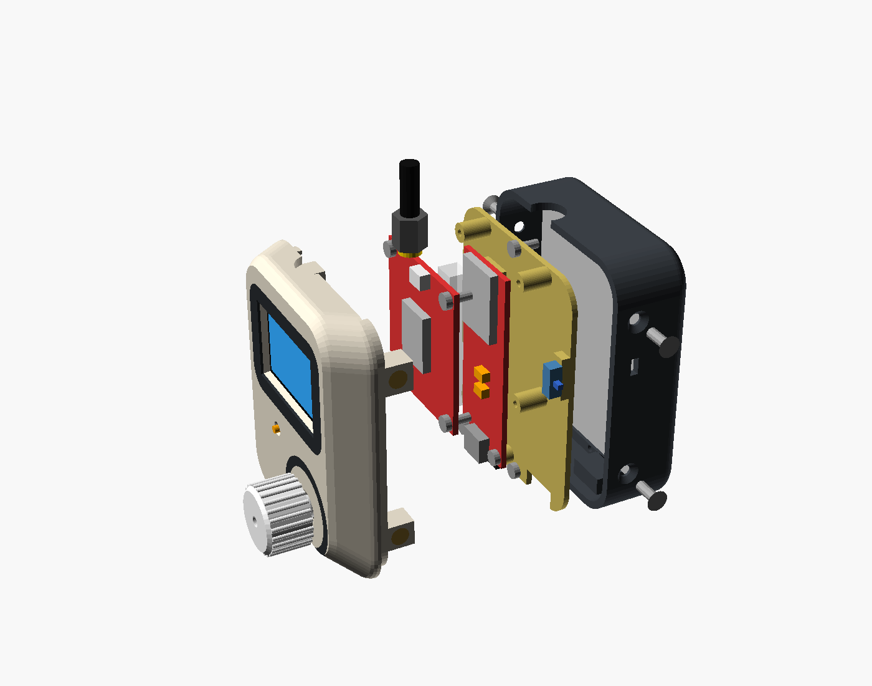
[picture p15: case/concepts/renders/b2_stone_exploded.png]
|  |  |  |  |  |

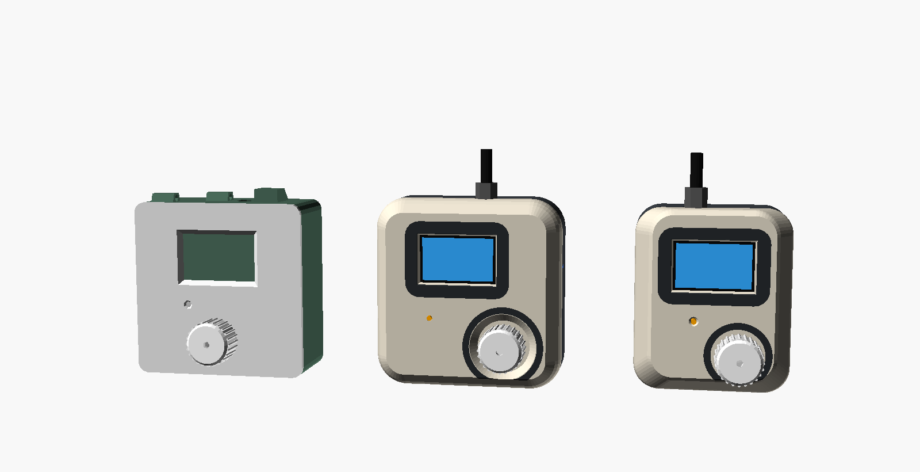
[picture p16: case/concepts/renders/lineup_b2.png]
lineup v0.1, B, B2

*To scale, left to right: v0.1, B, B2.*

**Outer size:** 63.0 x 75.5 x 32.6 mm, about 144 cm³, without the mount socket (the default for the first print). With it: 63.0 x 75.5 x 34.8 mm, about 153 cm³.

**Mount socket is optional.** `mount_socket = false` (the default) drops the TwistLock socket and its boss. The pouch then sits 0.4 mm off the inner floor (`batt_lift`) instead of 2.6 mm on the boss, and the back edge radius tightens from 6 to 3 mm so the pouch corners clear it. All fit checks pass both ways. To get the socket back, set `mount_socket = true`. The cart and strap renders are made with it on. The table and layer stack below describe the version with the socket. Without it, every height above layer 1 drops by 2.2 mm.

| | B | B2 | Change |
|---|---|---|---|
| Width | 79.4 | 63.0 | −16.4 mm |
| Height | 80.4 | 75.5 | −4.9 mm |
| Depth | 29.6 | 34.8 | +5.2 mm |
| Footprint area | 6,384 mm² | 4,757 mm² | −25% |
| Envelope volume | ~177 cm³ | ~153 cm³ | −14% |

**Layer stack.** Heights are above the inner floor; add 2.2 mm for the height above the outer back.

| Layer | Part | z (mm) |
|---|---|---|
| 1 | 2 Ah pouch, resting on the TwistLock socket boss (socket recess is 3.6 deep, plus a 1.0 mm skin) | 2.6–9.0, plus 0.6 swell allowance |
| 2 | Chassis plate | 9.6–11.2 |
| 2 | Thing Plus, on 2.4 mm standoffs over its microSD socket. Left side, USB-C at the bottom end, plug keep-out against the left wall. | board 13.6–15.2; tallest part 18.6; plug keep-out to 19.6 |
| 3 top | GPS. SMA edge 0.6 mm off the top wall, as in v0.1. | board 19.2–20.8; J4 to 23.8 |
| 3 top | OLED, in front of the GPS. Glass against the lid. | PCB 27.2–28.8; glass top 30.4 |
| 3 bottom | Twist, on its own, hung from lid bosses. Its encoder body bears on the lid, as in v0.1. The PCB overhangs the Thing Plus's right edge; the encoder pins sit over the bare plate. | PCB 21.0–22.6; encoder top 30.4 (= lid inner) |
| 4 | Lid | inner 30.4; face 32.6 |

**What sets the size:**
- **Width (58.6 mm inside)** is the pouch (55) plus 1.8 mm per side, so the plan corners can have an 8.5 mm inside radius.
- **Height (71.1 mm inside)** is set by the RESET plunger, not by the pouch. The Thing Plus RESET is fixed 28.2 mm from the USB end. Its plunger needs a straight path to the face, so the GPS has to start just above it (pin plus 0.6 mm gap = 29.9). Add 40.6 mm of GPS and the 0.6 mm SMA gap and you get 71.1.

  By coincidence, the pouch plus corner margins also comes to about 71. So tighter corners alone wouldn't shrink it.

**Checking the proposed layering against the numbers:**
- **"The battery sets the footprint."** Only for width. Height is set by the RESET-to-GPS column, as above.
- **Thing Plus on the left, USB-C at the bottom.** Yes. Its plug keep-out faces the left wall.
- **GPS SMA against the top wall.** Yes, at 0.6 mm as in v0.1. I checked the jack that hangs 2.4 mm below the board at its axis: it sits at y ≥ 70.5, beyond the Thing Plus's far end at 60.9, and above the plate.
  J4 can't be used with only 0.6 mm to the wall, so the design uses the GPS's other Qwiic port.
- **Twist alone in the bottom zone.** Yes. The Twist sits 1.35 mm right of the plunger pin, and its lid bosses clear the plunger's guide tube by 0.5 mm. The GPS sits 0.6 mm above the pin.
  The two zones share the depth as you proposed: the encoder top and the OLED glass top both sit at the lid's inner face.
- **Target ~62 x 70.** I got 63 x 75.5. The 5.5 mm of extra height is the RESET path.

  One option to cut it, which I didn't model: rotate the GPS so the SMA comes out of the upper right side. That should save roughly 3 mm of height (38.4 mm of GPS instead of 41.2 in that column), at the cost of the antenna cable leaving from the side.

**The dial.** The concept had a 2.4 mm dial cup, which cost no depth. The print version drops it, for two reasons:
- **Twist screw heads.** With the cup, the Twist sat 0.4 mm above the Thing Plus. The screw heads under its left-hand holes (1.75 mm tall) had nowhere to go, because those holes sit over the Thing Plus.
- **A 20 mm ceiling.** The cup's floor was a 20 mm ceiling in the face-down lid print.

Raising the Twist until the encoder bears on the lid fixes both, and it's v0.1's proven arrangement. The knob sits 2 mm off the flat face, as in v0.1, inside a dark printed ring.

I also rejected a raised guard ring around the knob. It would be a raised feature on the face, and the face-down lid can't print one without supports.

**Less blocky.** The battery limits the plan corners to an 8.5 mm inside radius, so the softness comes from the section, shaped like a lens:
- **Back:** flat (the pouch spans the full width), with a 6 mm edge radius and a 45° printable lead-in.
- **Sides:** straight up to a shoulder 3 mm above the Thing Plus's tallest part (z 21.6).
- **Lean:** above the shoulder, the left, right and bottom sides lean 4.9 mm inward over a 7 mm rise. That's 35° from vertical on the sides and 44.7° on the diagonal at the bottom corners, where the two leans add. The face is therefore 9.8 mm narrower than the back.
- **Top:** no lean, because the SMA, J4 and the OLED's top ears are within 2 mm of the top wall.

The parts would allow about 9 mm of lean. Printing is what limits it. I first used 6 mm, but at the bottom corners the diagonal flank was then 50.5°, which can't print face-down. 4.9 mm keeps that diagonal at 44.7°.

**No wedge.** I decided against a wedge, and the direction matters:
- **Thicker at the dial (bottom) end** tilts the screen *away* from someone looking down at a device held at waist height.
- **Thicker at the top end** tilts it toward you, but it adds depth to the OLED/GPS zone, which is already the deepest part.

The cart knuckle provides tilt when mounted.

**Where everything is:**

| Item | Location |
|---|---|
| Dial | Lower right. Centre 19.1 mm from the right edge and 16.9 mm from the bottom. |
| RESET | Lower left, beside the dial |
| USB-C and microSD | Bottom end |
| SMA | Top end, left of centre |
| EN switch | Right side, at layer 2 height |
| Wrist-strap holes | Bottom end, right of the port bay |
| Lid screws | Three M3 countersunk: one at the right side low, one at each side high |
| TwistLock socket | Centre of the back |

I verified all of these in the cart scene, with the same 55° and 25.4 mm bar check as before.

**Printability (PETG on the X2D, no supports):**
- **Back shell:** prints back-down, with vertical walls up to the shoulder.
- **Lid:** prints face-down. Its flanks widen at 35° (44.7° at the bottom corners) as it prints.
- **Plate:** prints flat. It carries the Thing Plus standoffs and three GPS standoffs, which are 8 mm tall.

Details and the overhang audit are in [Printing B2](#printing-b2).

**Unverified:**
- **Thing Plus parts under the Twist.** The Twist PCB overhangs a 7 mm strip along the Thing Plus's right edge. Its two left screw heads sit 0.65 mm above the 3.4 mm part height I've assumed for the Thing Plus throughout.
- **GPS mounting.** The fourth GPS mounting hole sits over the Thing Plus, so the GPS is held by three plate standoffs. The OLED and lid stop it from tipping.
- **GPS Qwiic.** The design uses the GPS's other Qwiic port, as in A. Its position needs checking.
- **Assembly order and cables.** The Qwiic cables now fold between layers 2 and 3. See [Printing B2](#printing-b2).
- **Plug keep-out.** The 7 mm Thing Plus keep-out is still an assumption.

  If the real JST plug sits lower on the board, I can't fix that by sliding the Thing Plus: RESET is fixed relative to the board, and the Thing Plus already sits against the keep-out on its left. It would only free up room on the left side.
- **Battery.** Per your call, the 2 Ah pouch stays. A ~1 Ah cell wouldn't meaningfully shrink B2: the inside width is also set by the RESET-plus-Twist row (about 57 mm), and the height by the RESET-plus-GPS column (71 mm). It would save at most about 1.5 mm of width and a fraction of a millimetre of depth.

## Printing B2

`concept_b2_stone.scad` is the source. `./export_b2.sh` writes the five print parts, already in print orientation, to `stl_b2/`. `render_all.sh` runs it as well.

The default is **without the mount socket** (`mount_socket = false`). To print the socket version, run `./export_b2.sh -D 'mount_socket=true'`.

| STL | Orientation | Size (mm) | Notes |
|---|---|---|---|
| `back_shell.stl` | Back down | 63.0 x 75.5 x 21.6 | Pouch tray, plate ledges, wrist-strap block, side-screw countersinks |
| `lid.stl` | Face down | 63.0 x 75.5 x 21.4 | Face, OLED and Twist bosses, RESET guide tube, locating lip, 4 tabs (3 with inserts), port-bay tooth |
| `plate.stl` | Flat | 57.8 x 70.3 x 9.6 | Thing Plus standoffs and far-end rest, 3 GPS posts, switch shelf |
| `knob.stl` | Upright | 19.2 x 19.2 x 12.0 | v0.1's `knob()`, unchanged |
| `plunger.stl` | Tip down | 3.4 x 3.4 x 15.8 | RESET plunger |

Each STL is a single solid in which every edge has exactly two faces, counted with vertices rounded to 1e-6 mm.

| STL | Edges | Faces per edge |
|---|---|---|
| back_shell | 4434 | all 2 |
| lid | 6876 | all 2 |
| plate | 2274 | all 2 |
| knob | 2586 | all 2 |
| plunger | 585 | all 2 |

All five also slice in Bambu Studio 02.08.02.61's CLI (`--slice 0`) with return code 0 and no warnings. That was with the CLI's default printer and filament profile, not an X2D/PETG profile. Default-profile times: back shell 2 h 36 min, lid 2 h 00 min, plate 1 h 00 min, knob 16 min, plunger 2 min (the slicer added a brim).

### Print settings (Bambu X2D, PETG)

- 0.4 mm nozzle, 0.2 mm layers, 3–4 walls, 20% gyroid, no supports (as v0.1).
- **Lid:** face down on a textured PEI plate. The dark screen panel and dial ring are the top 0.6 mm of the face, so the X2D's second nozzle can print them as the first three layers. Or print the lid in one colour.
- **Plunger:** 0.12 mm layers, as in v0.1. It stands on a 1.2 mm tip, so give it a brim, or print several at once.
- **Knob:** clear or translucent PETG, so the encoder's RGB shows through the centre light pipe (as v0.1).

### Hardware

| Qty | Item | Where |
|---|---|---|
| 3 | M3 heat-set insert, 4.0 mm hole, ≤ 5.8 mm long (v0.1 size) | Lid tabs: right low, left high, right high |
| 3 | M3 x 8 countersunk (ISO 10642 flat head) | Through the shell's side walls into those inserts |
| 2 | M2.5 x 5 pan head, self-tapping into PETG | Thing Plus to plate standoffs |
| 3 | M2.5 x 6 pan head | GPS to the three plate posts |
| 4 | M2.5 x 5 pan head | Twist to lid bosses, from behind. Not 8 like v0.1: the lower holes sit under the leaning flank. |
| 4 | M2.5 x 4 pan head | OLED ears to lid bosses (as v0.1) |
| 2 | M2.5 x 6 pan head | Plate to the bottom and top ledges |
| 1 | SS12D00G3-style slide switch plus ~6 cm of 28–30 AWG wire | Right wall slot, hot-glued to the plate's switch shelf (as v0.1) |
| | Qwiic cables | Thing Plus → GPS → OLED → Twist |

Every screw length is set so the screw **can't reach a skin, a board or the pouch**:
- Each screw is modelled as a solid (head, shank and insert body) and included in the fit checks.
- Each pilot hole stops at least 0.6 mm short of an outer face.
- A longer screw fails a check. For example, an M2.5 x 7 in the Thing Plus would reach the pouch, an M2.5 x 7 in the OLED would come out of the face, and an M2.5 x 8 in the Twist (v0.1's length) would come out of the bottom flank.

### Where this differs from v0.1, and why

- **Lid retention.** v0.1 hooks two lid tongues under the top wall and puts two M3 screws through the back into the lid. Neither works in B2:
  - **Back screws:** the pouch fills the floor to within 1.8 mm of the side walls, so there's no room for back-to-lid screw posts.
  - **Tongues:** the GPS edge sits 0.6 mm from the top wall, right where they'd go.

  So instead, four tabs on the lid drop inside the back shell, and M3 x 8 countersunk screws go horizontally through the side walls into heat-set inserts in three of the tabs.

  The fourth (lower-left) tab has no screw. A screw head there would sit on the bottom-left corner curve and stand up to 1 mm proud, and the Thing Plus plug keep-out blocks the straight wall above it. That tab still locates the lid and clamps the plate.

  The lid also has a locating lip (v0.1's 0.2 clearance, 1.2 thick, 3 deep), notched where the GPS edge, the SMA, the Twist corner and the USB port bay are.
- **Lip and tabs fused into the lid.** Above the rim the lid wall leans inward, so a plain lip and tabs would join it only along a knife edge, and the lip would print as a loose ring. So the lid is built by subtracting one cavity:
  - Inside the lip, the cavity is the lip's inner outline.
  - Above the rim, it's a convex hull from that outline up to the lid's own inner wall, 2.4 mm higher. That thickens the wall just above the rim, with a face about 7° off vertical on the leaning sides and 30° on the top side.

  The lip, tabs and tooth overlap the lid by 0.3 mm. No feature touches another edge-to-edge.
- **Plate.** v0.1 screws its plate onto three floor pillars, but B2 has no free floor beside the pouch. Instead the plate:
  - rests on ledges along the bottom wall, the top wall and the right wall;
  - is held by two M2.5 x 6 pan screws into the bottom and top ledges;
  - is clamped down by all four lid tabs.

  There's no left ledge, because the pouch lead runs up the 1.8 mm left margin to the plate's lead notch (v0.1's notch position, under the Thing Plus JST).

  The Qwiic cables don't cross the plate. The Thing Plus, GPS, OLED and Twist are all above it, and the cables run up the left plug channel.
- **Twist.** It hangs from four lid bosses and its encoder bears on the lid, as in v0.1. It can't sit on plate standoffs, because its left-hand holes are over the Thing Plus.
- **USB-C and microSD.** They share one "port bay" that's open up through the shell rim, so the back shell has no 12.6 mm bridge over the opening. A tooth on the lid fills the top of the slot.

### Overhang and bridge audit

I checked every downward-facing surface steeper than 47° from vertical in each STL, in print orientation.

| Part | What's left (all acceptable) |
|---|---|
| Back shell | The EN slot's 4.8 mm bridge; tops of the Ø3.4 side-screw holes; teardrop tips on the wrist-strap holes |
| Lid | The tops of the three Ø4 horizontal insert holes; one 2 mm ceiling at the Twist-corner lip notch |
| Plate | Nothing |
| Plunger | Nothing. The collar has a 45° underside. |
| Knob | The 6.2 mm bore ceiling (v0.1 part) |

Things I fixed to get there:
- A 50.5° lean at the lid's bottom corners
- The knife-edged lip, and the coincident faces where the lip met the thickened wall. The latter left 114 kissing edges in an earlier lid STL; it now has 0.
- A 12.6 mm bridge over the USB-C opening
- Round wrist-strap holes (now teardrops)
- The dial cup's 20 mm ceiling

### Fit checks

These all run in the `.scad` file, and every one exports empty or zero-volume, both with and without the socket.

| Part | What it checks | Result (total overlap) |
|---|---|---|
| `chk` | Shell + plate against every component | 0.0000 mm³ |
| `chk_out` | Components + screws outside the outer skin | 0.0000 mm³ |
| `chk_comp` | Every pair among the 17 solids: boards, pouch, switch, plunger, plate, lid, shell features, 6 screw groups, inserts. 15 intended contacts are exempt (e.g. a screw in its own pilot). | 0.0001 mm³ |
| `chk_plate` | Plate against the shell and lid | 0.0000 mm³ |
| `chk_pilot` | Pilot holes against the outer 0.4 mm skin and the pouch | empty |
| `chk_cart` | Device against the cart clamp and bar (socket version) | empty |

**Deliberate failures,** each of which trips its check:

| Change | Check | Overlap |
|---|---|---|
| OLED screw M2.5 x 7 | `chk_out` | 30 mm³ |
| Twist screw M2.5 x 8 | `chk_out` | 0.26 mm³ |
| Thing Plus screw M2.5 x 7 | `chk_comp` | 13 mm³ |
| Side screw M3 x 12 | `chk_comp` | 8.8 mm³ |
| Screw added to the lower-left tab | `chk_out` | 8.3 mm³ |
| Tabs pushed 1 mm into the plate | `chk_plate` | 192 mm³ |
| Lean of 9 mm | `chk` | 23 mm³ |
| Cart clamp too close | `chk_cart` | 433 mm³ |

**Correction to earlier B2 results.** Until this revision, a dangling-`else` bug in the file meant `chk_out`, `chk_plate` and `chk_cart` never actually ran for B2: they returned empty no matter what. They now run, and they caught three real problems that are fixed above: Twist screws through the flank, side-screw heads on corner curves, and pilots through the skin.

### Assembly order

1. **Lid.** Press the 3 M3 inserts into the lid tabs (lid on its side, iron horizontal).
2. Screw the OLED (glass against the lid) with 4 x M2.5 x 4.
3. Screw the Twist with 4 x M2.5 x 5 from behind, encoder through its hole. Connect Qwiic OLED → Twist.
4. Drop the RESET plunger into its tube from inside. Its collar keeps it from falling out the front.
5. **Back shell.** Lay the pouch in, with its lead running up the left margin.
6. **Plate.** Screw the Thing Plus (2 x M2.5 x 5) and the GPS (3 x M2.5 x 6) to the plate.
7. Solder the EN switch to the Thing Plus EN and GND pins. Connect Qwiic Thing Plus → GPS.
8. Drop the plate in, feeding the pouch lead up through the left notch to the Thing Plus JST. Screw it down with 2 x M2.5 x 6.
9. Set the switch actuator into its slot and hot-glue the switch to the shelf and wall.
10. Connect Qwiic GPS → OLED. Lower the lid straight down, with the lip inside the shell, then fit 3 x M3 x 8 countersunk screws through the sides.
11. Press the knob on (2 mm clear of the face). Screw on the antenna.

### Measure before you print

1. **Thing Plus plug keep-out.** I assumed the JST and Qwiic plugs need 7 mm along the left edge, from 8 to 50 mm from the USB end. Check the real positions. If the keep-out starts higher up the board, the lower-left tab could take a fourth screw.
2. **Thing Plus parts under the Twist.** In Thing Plus board coordinates, that's the strip 15.7–22.9 mm across and 0–25 mm from the USB end. The Twist PCB and its two left screw heads sit 0.65 mm above a 3.4 mm part height. Anything taller there collides.
3. **The GPS's other Qwiic port.** The top-edge J4 is unusable, 0.6 mm from the wall. Where the other port sits decides the GPS-to-OLED cable route.
4. **3-post GPS mounting.** The fourth GPS hole is over the Thing Plus and gets no post. Check the GPS doesn't rock. If it does, a dab of foam or hot glue on its corner over the Thing Plus fixes it.
5. **The pouch.** Check it fits the 55 x 64 x 6.4 pocket. Check its lead exits where it can run up the left margin; there's 1.8 mm between the pouch and the left wall.
6. As in v0.1, also check:
   - the OLED glass and tape thickness (1.6 mm);
   - the encoder body (12.4 x 13.4 x 7.8) and shaft length (10 mm above the body);
   - the slide switch size;
   - whether the SMA plug threads fully (0.6 mm board-to-wall gap, 11 mm port).

**Fit print first.** Print only `plate.stl`: about 7 cm³, the quickest part. Screw the Thing Plus and GPS onto it. That checks the standoff and post positions, the 3-post GPS mount, the plug keep-out along the Thing Plus's left edge, and the clearance under where the Twist will sit.

Next, print `back_shell.stl` to try the pouch and the plate in the tray before committing to the lid.

---

## Shared mount: "TwistLock"

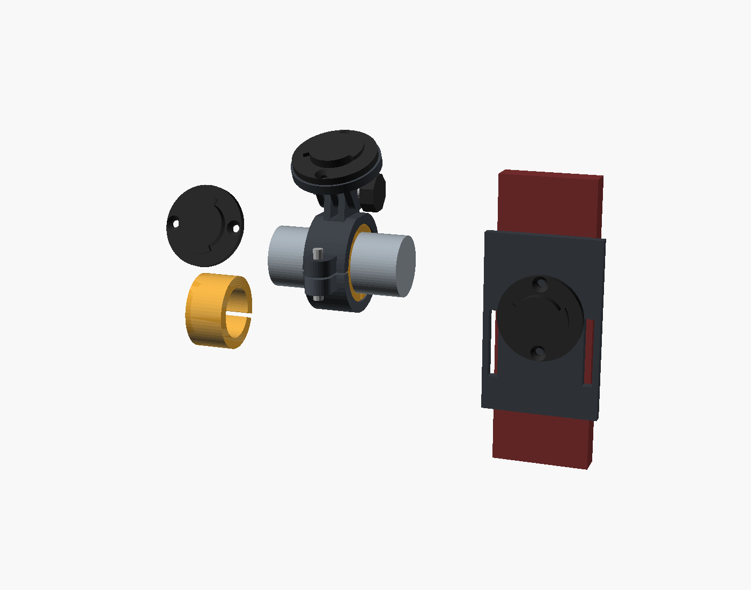
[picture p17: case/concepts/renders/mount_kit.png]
mount kit

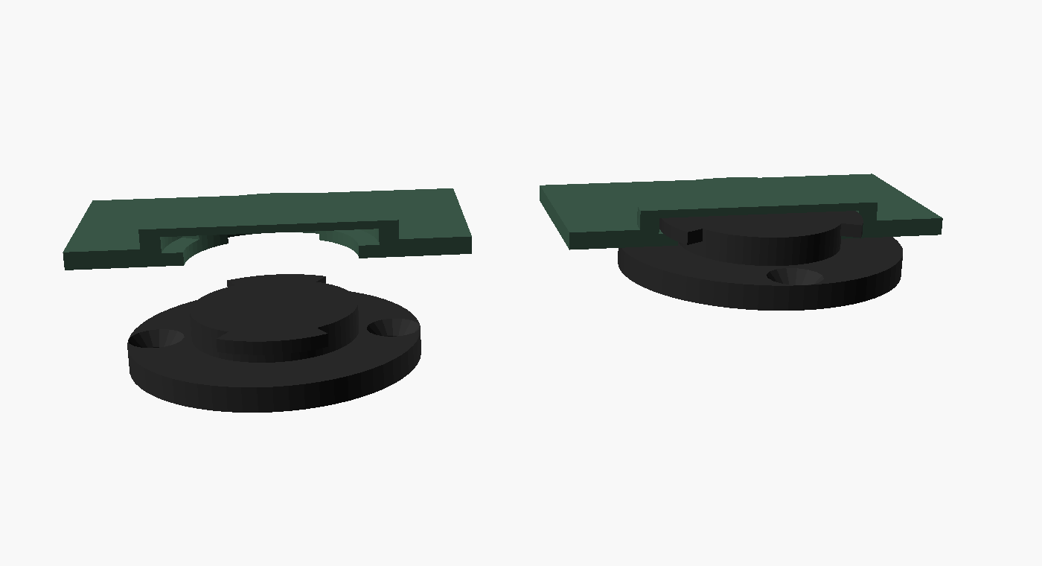
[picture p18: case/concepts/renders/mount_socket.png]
socket


**Device side.** A recessed quarter-turn socket in the back, so the back stays flush and nothing digs into your palm. The recess is 3.6 mm deep, 4.6 mm including the skin behind it:
- The opening is a 20.6 mm neck hole with two lug notches.
- Behind the 1.6 mm lip is a 25.6 mm chamber with rotation stops at 90°.
- A detent bump on each lug clicks into a dimple in the chamber ceiling. The detent isn't modelled.

**To mount:** push the device onto the puck with the screen turned sideways, then twist 90° until it stops and the screen is upright.

**Mount side.** One male **puck** (35 mm flange, 20 mm neck, two 60° lugs on a 25 mm circle, 2x M3 countersunk). The same puck screws onto:
- **Cart-bar clamp.** Two halves with a 32.5 mm bore, held by 2x M4 x 25 bolts and nuts. Split TPU shims step the bore down to 25.4 mm (1") or 22.2 mm (7/8"), which covers the 22–32 mm range. A GoPro-style 2/3-prong knuckle with an M5 bolt and thumb nut sets the screen tilt toward you. The renders use 55°.
- **Bag-strap clip.** A 48 x 74 plate with a spring tongue for straps up to 12 mm thick, with a lead-in and a retaining ridge. Two side slots take a 25 mm hook-and-loop strap for padded straps, bag handles, or square riding-cart struts.

| Push-cart bar, A | Push-cart bar, B | Bag strap, A | Bag strap, B |
|---|---|---|---|
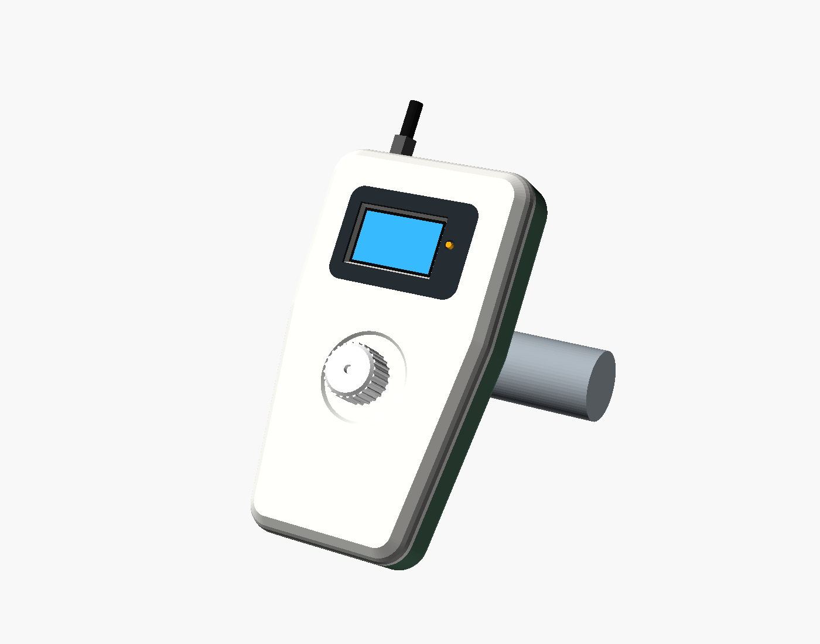
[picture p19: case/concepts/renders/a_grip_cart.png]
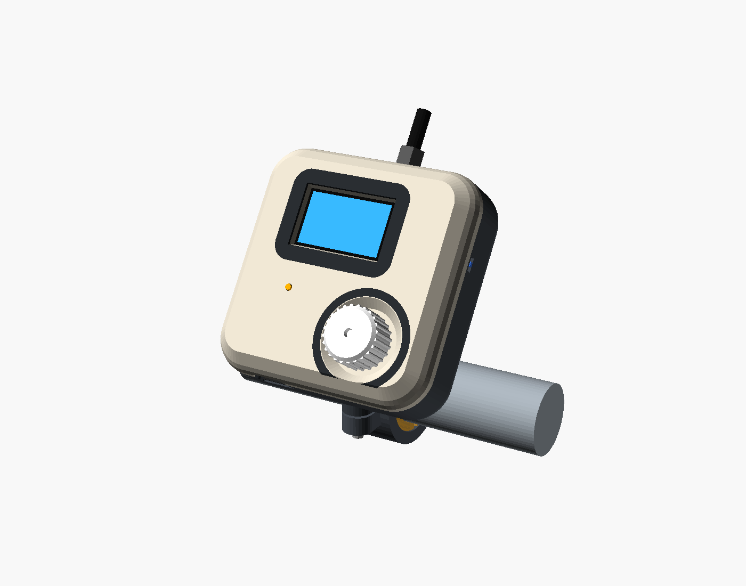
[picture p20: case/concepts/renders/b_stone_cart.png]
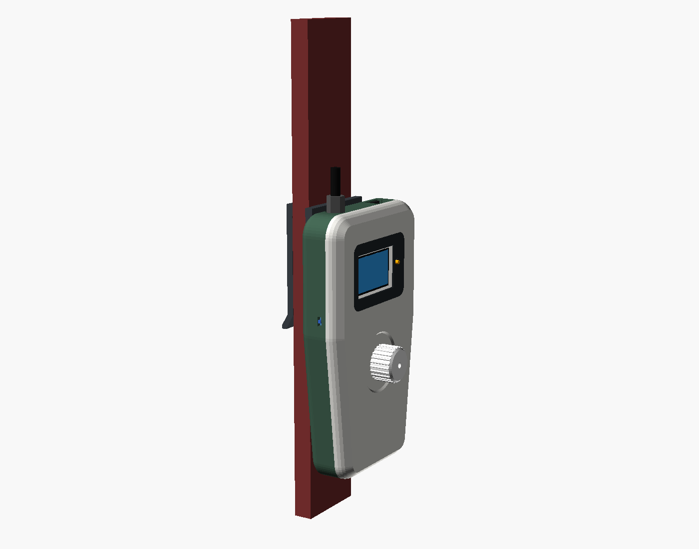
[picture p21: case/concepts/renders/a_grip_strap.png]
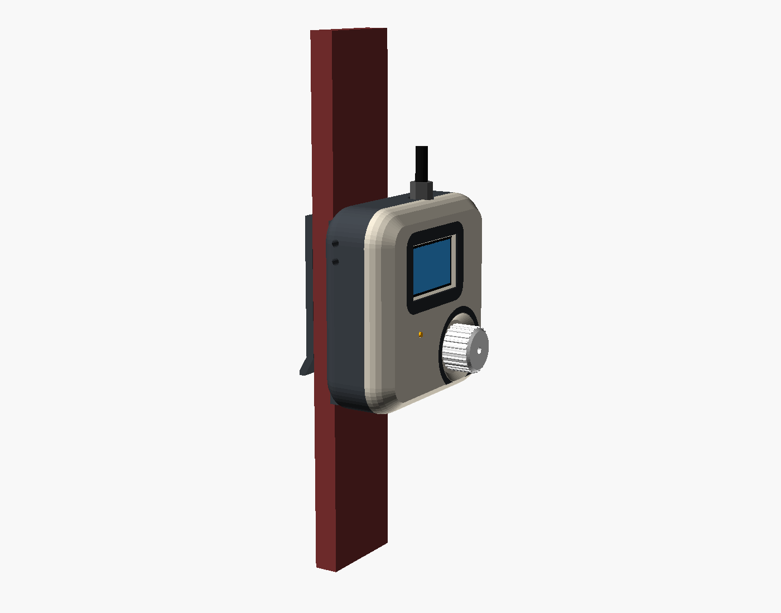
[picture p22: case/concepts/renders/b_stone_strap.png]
|  |  |  |  |

Side views: [A on the cart](renders/a_grip_cart_side.png), [B on the cart](renders/b_stone_cart_side.png).

**Printing, all PETG, no supports:**
- **Puck:** lugs down. The flange needs a 45° underside chamfer, which isn't modelled.
- **Clamp halves:** split face down, so the knuckle prongs stand vertical.
- **Tilt head:** prongs down.
- **Strap clip:** on its side, because its U-profile is a plain extrusion.
- **Shims:** TPU.

**Honest caveats:**
- **The strap clip's spring tongue may relax.** PETG creeps under constant load, especially in a hot car. The hook-and-loop slots are the backup.
- **Garmin compatibility isn't verified.** The device-female, mount-male convention is the same as Garmin's bike-computer mounts, but I didn't check these sizes against a real Garmin mount. Matching them would let you use cheap off-the-shelf Garmin-style bar mounts.

---

## Comparison

| | v0.1 | **A Grip** | **B Stone** | **B2 Stone, layered** |
|---|---|---|---|
| Outer size (mm) | 74.4 x 78 x 31.6 | 78.6 (62.6 at the handle) x 138.3 x 22.8 (+3.5 pad) | 79.4 x 80.4 x 29.6 | 63.0 x 75.5 x 34.8 |
| Envelope | ~175 cm³ | ~223 cm³ | ~177 cm³ | ~152 cm³ |
| Internal layout | Stacked (plate over the pouch, Twist over the boards) | Two zones, side by side | Stacked, Twist beside the GPS | 4 layers; GPS + OLED and Twist share layer 3 |
| One-handed use | Box held flat, dial centred | **Best:** remote-style grip, thumb dial, screen never covered | Good: palm stone, right-thumb dial | Good: smaller palm stone, right-thumb dial, leaning sides |
| Mounted | None (flat back) | Good: socket in the head, handle hangs | **Best:** compact and centred | **Best:** smallest face area |
| Pocketability | OK | Jacket pocket only | Good (no corners, knob in a cup) | Good: smallest footprint, but the deepest |
| Supports needed (X2D, PETG) | None | None | None | None (35° flanks, 44.7° at the bottom corners) |
| Parts | Shell, lid, plate, knob, plunger | Shell, lid, knob, plunger, TPU pad (no plate) | Shell, lid, plate, knob, plunger | Same as B |
| Layout risk | Proven | Medium (new layout, plug keep-out and cable lengths to verify) | **Low** (v0.1 stack) | Medium (Twist overhangs the Thing Plus, GPS on 3 posts, cables fold between layers) |
| Fit check (no parts through the shell) | ✓ | ✓ | ✓ | ✓, plus a component-to-component check |

## Recommendation

**Go with Concept A, the Grip, plus the TwistLock kit.**

You asked for a better handheld that also works mounted, and the Grip is the only one that changes how the device feels in the hand. You hold it one-handed with your thumb on the dial, and the screen stays clear above your hand. It's also the thinnest. The extra length is the price, and the mount handles it fine.

**Before committing,** print just the outer body of A as a quick, low-quality draft (or the shell and lid with no internals) to judge the length in your hand. Then measure the Thing Plus JST and Qwiic positions and check the Qwiic cable lengths. Those are the only things that could force a re-layout.

**If 138 mm feels too long,** B is the safe fallback. It reuses v0.1's internal stack (the least risk) and still fixes the "basic box" look, the knob, and the mount.

**Update:** you chose B. Its layered iteration, B2, is described above.

## Ideas I considered and dropped

- **Slim landscape slab (everything in one layer).** The Twist stack sets a depth of about 22 mm whenever the dial sits over a board or the pouch. Getting thinner would mean giving the Twist its own floor area, which makes the slab about 158 mm wide. A already captures most of the "slimmer" benefit.
- **Angled screen.** The screen sits above the dial, so tilting it toward your eyes means making the top end thicker, about 6 mm for every 10°. The cart mount's tilt knuckle gives the angle where it matters most. In the hand, your wrist does it for free.
- **Rotating bezel or side thumbwheel.** The Qwiic Twist is a shaft encoder with an axial push switch. A bezel or thumbwheel would need gears and would lose the click.
- **Round puck.** The pouch's diagonal (85 mm) forces a diameter of about 95 mm or more.
- **Smaller battery.** It wouldn't shrink B, because the side-by-side boards set B's width. For A, a 1.2 Ah 34 x 62 pouch could narrow the handle to about 42 mm. That's unverified and roughly halves the runtime, so I left it out.

## Files

| File | What it is |
|---|---|
| `concept_a_grip.scad` | Concept A. `part` = `assembly`, `exploded`, `cutaway`, `cart`, `strap`, `outer`, or the checks `chk`, `chk_out`, `chk_pad`, `chk_cart`. |
| `concept_b_stone.scad` | Concept B. `part` = `assembly`, `exploded`, `cutaway`, `cart`, `strap`, or the checks `chk`, `chk_out`, `chk_plate`, `chk_cart`. |
| `concept_b2_stone.scad` | Concept B2, print-ready. Views: `assembly`, `exploded`, `cutaway`, `side`, `cart`, `strap`. Print parts: `back_shell`, `lid`, `plate`, `knob`, `plunger`. Checks: `chk`, `chk_out`, `chk_comp`, `chk_plate`, `chk_pilot`, `chk_cart`. |
| `export_b2.sh` | Exports B2's print parts to `stl_b2/`. |
| `stl_b2/` | B2 print STLs, in print orientation. |
| `mount_kit.scad` | The TwistLock kit (`part="kit"`) and the socket and puck engagement detail (`part="socket"`). |
| `lineup.scad` | To-scale lineups: `part="all"` is v0.1, A and B; `part="b2"` is v0.1, B and B2. It uses `../cad/shot_tracker_case.scad` read-only. |
| `lib/components.scad` | Component sizes and ghost models, copied from v0.1. |
| `lib/shape.scad` | Rounded-body helper (`pebble`, with the exact inset used for the cavity), window, and strap-hole cuts. B2 builds its lens body from the same `corner_ring` pieces. |
| `lib/mount.scad` | Socket cutter, puck, bar clamp, shims, tilt head, strap clip. |
| `render_all.sh` | Regenerates everything in `renders/`. |

**Fit check:** for example, `openscad -D 'part="chk"' -o chk.stl concept_a_grip.scad`. It should come back empty or zero-volume. `chk_out` should be empty.

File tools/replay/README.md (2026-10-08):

# Round replay viewer

A single static page that replays a round exported from the shot tracker on a satellite map, shot by shot.

## Open it

- **From disk:** open `tools/replay/index.html` in a browser. No server or build step.
- **Served:** any static server works, e.g. `python3 -m http.server -d tools/replay`.
- **Load a round:** drop a file on the page or use *Open file…*. Use the output of `geojson <id>` or `csv <id>` from the USB serial console (see [firmware/README.md](../../firmware/README.md#exporting-rounds-usb-serial-115200)). Stray serial prompt lines around the export are fine.
- **Load sample** replays an embedded copy of `samples/sample-round.geojson`, a synthetic round (a real round moved to another location, rotated and re-timed). Deep links: `index.html#sample`, `#sample&shot=9`, `#sample&play`.

It needs a network connection for Leaflet (cdnjs) and the Esri World Imagery tiles. Offline, the scorecard and stats still work, but there's no map.

## Controls

| Key | Action |
|---|---|
| `←` / `→` | Previous / next shot |
| `↑` / `↓` | Previous / next hole |
| `Space` | Play / pause |
| `O` | Overview of the whole round |

You can also click a dot on the timeline, a scorecard row, a tee marker or a shot on the map.

## How shots are drawn

- **Full shots** fly from start to landing as an arc, with a ground shadow and a trail. Then the camera moves to the next shot.
- **Putts** only record where they were struck. A putt rolls to where the next stroke on the same hole started, because that's where the ball stopped. The last putt on a hole pulses in place. *Hole out* doesn't record a position, so the cup location can't be derived.
- **Full shots with no landing** (an unfinished or in-flight shot): if the next stroke on the hole has a position, a dashed line goes there with an approximate (`~`) distance. Otherwise the shot pulses in place.
- **Shots saved without GPS** count as strokes in the scorecard and timeline, but there's nothing to draw. The map shows a note instead.

## GeoJSON vs CSV

Both formats come from `storage.h` and parse to the same shots:

- **CSV is complete.** Every stroke gets a row. A row with no GPS has empty coordinates.
- **GeoJSON drops shots that have no start fix.** The viewer spots gaps in the per-hole `shot` numbers and adds those strokes back with an unknown club. A no-GPS shot that's the *last* stroke on a hole leaves no gap, so it can't be detected. Use the CSV if that matters.
- **Units:** GeoJSON states them (`"units"`). CSV doesn't, so the viewer compares distances with the coordinates to tell yards from metres.
- **Round status:** neither export says whether the round was finished, so the last hole is shown as recorded. A round's `startUnix` is `0` when GPS time wasn't known at the start. The viewer uses the first shot time instead.

## Tests

```sh
node tools/replay/parse.test.mjs
```

The parser lives inline in `index.html` as a classic `<script id="replay-parser">`. ES module imports fail from `file://` in Chrome, so it isn't a separate module. The test extracts that block, runs it in a Node VM and checks the following:

- `samples/sample-round.geojson` and `samples/sample-round.csv` give identical shots: 5 holes, H1=4, H2=4, H3=2, H4=4, H5=4, 18 strokes.
- The embedded sample matches `samples/sample-round.geojson`.
- Edge cases parse correctly: no-GPS shots, numbering gaps, putt-only holes, serial noise, and empty or invalid files.

If you change the embedded sample, keep it identical to `samples/sample-round.geojson` or update the test.

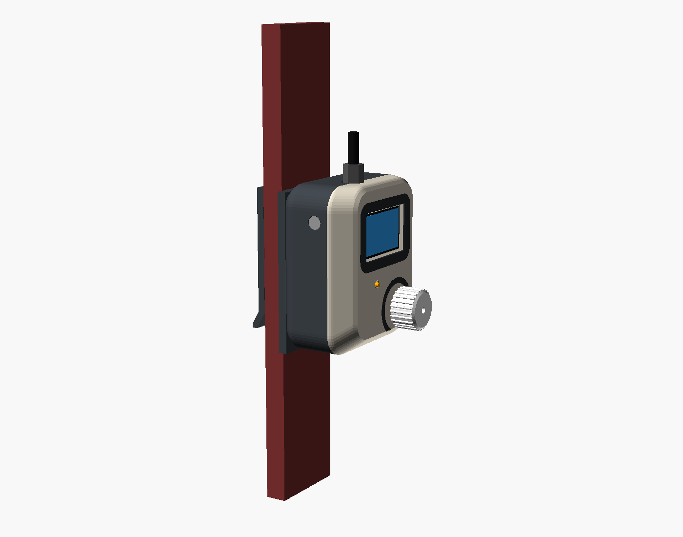
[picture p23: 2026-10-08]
case/concepts/renders/b2_stone_strap.png

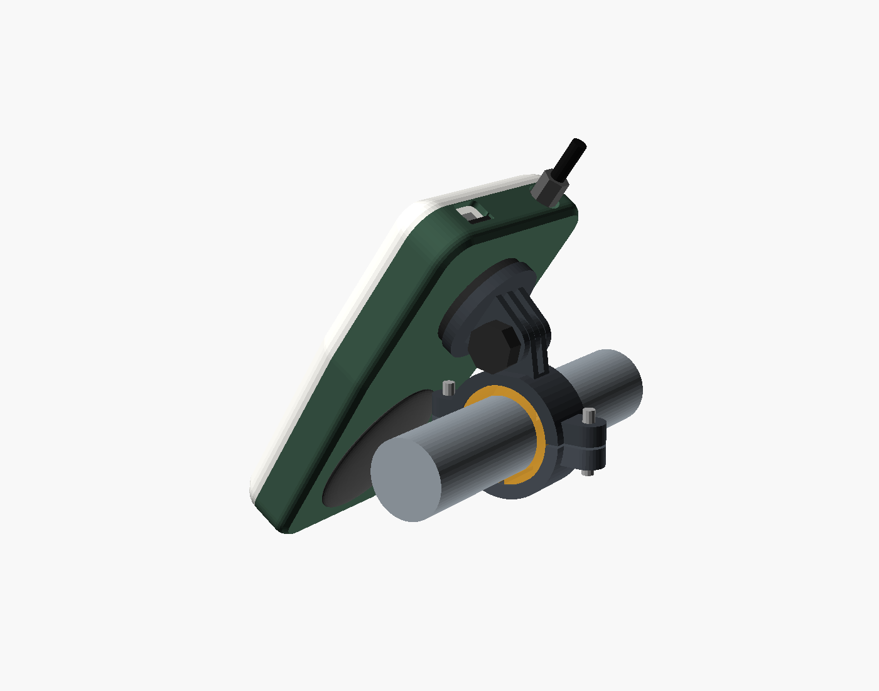
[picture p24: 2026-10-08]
case/concepts/renders/a_grip_cart_side.png

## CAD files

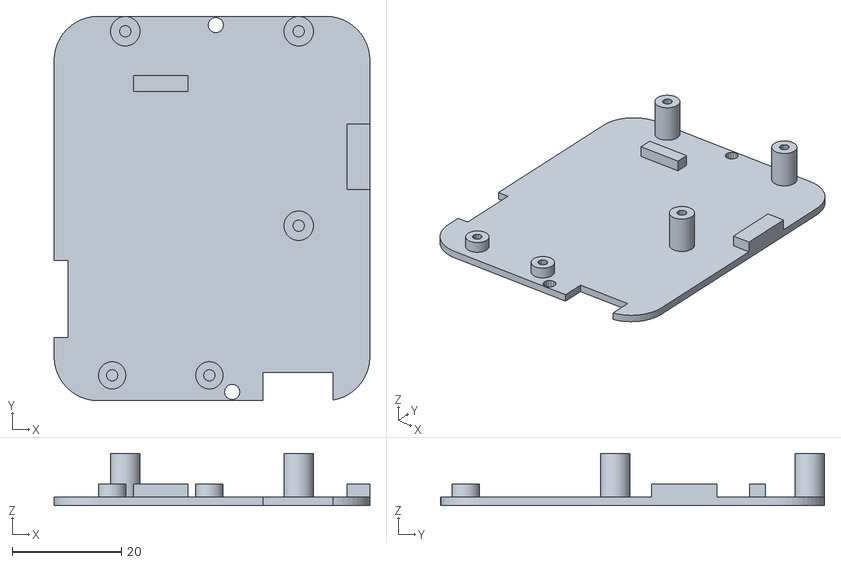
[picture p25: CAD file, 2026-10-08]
case/concepts/stl_b2/plate.stl
57.8 x 70.3 x 9.60

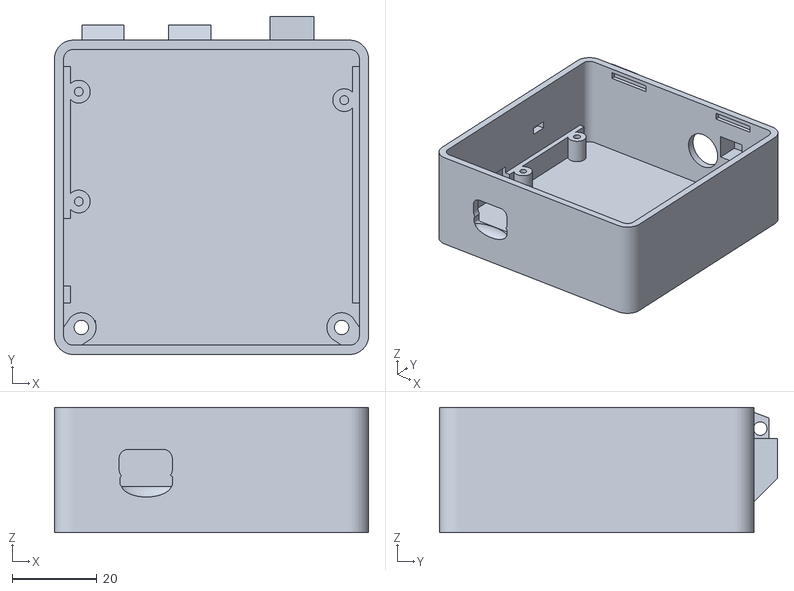
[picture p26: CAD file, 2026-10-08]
case/stl/shell.stl
74.4 x 80.0 x 29.6

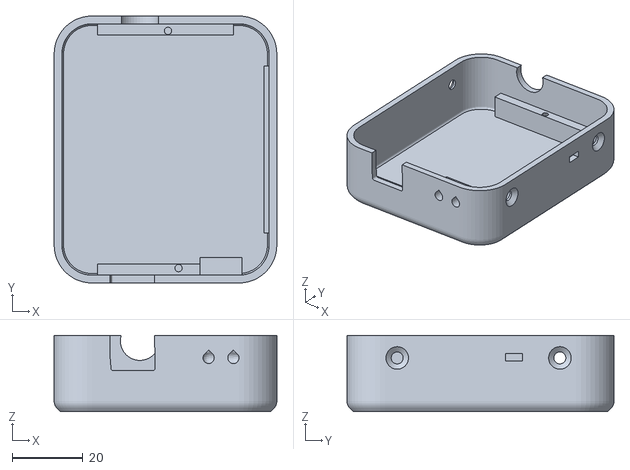
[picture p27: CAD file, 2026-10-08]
case/concepts/stl_b2/back_shell.stl
63.0 x 75.5 x 21.6

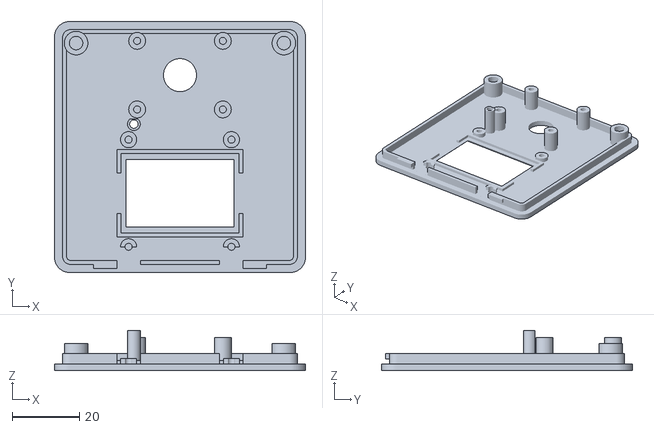
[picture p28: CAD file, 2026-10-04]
case/stl/lid.stl
74.4 x 74.4 x 11.9

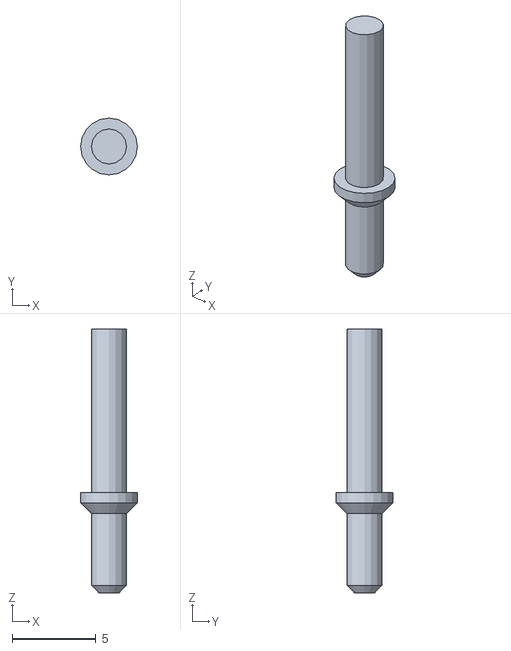
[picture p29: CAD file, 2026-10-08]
case/concepts/stl_b2/plunger.stl
3.40 x 3.40 x 15.8

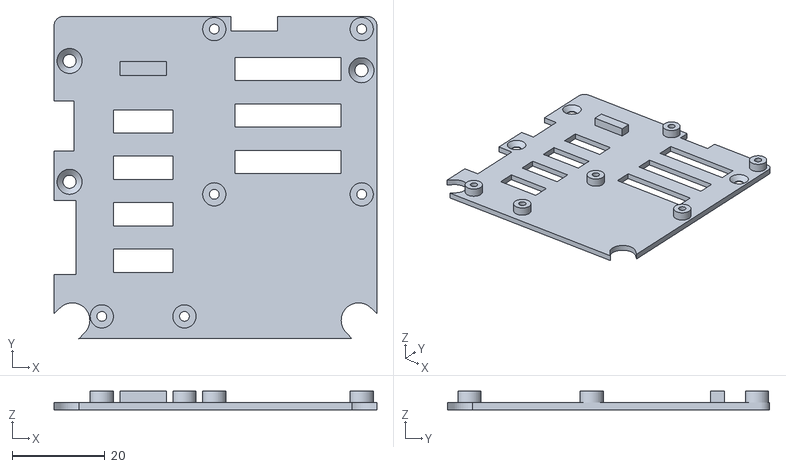
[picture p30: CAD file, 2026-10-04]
case/stl/plate.stl
69.5 x 69.3 x 4.00

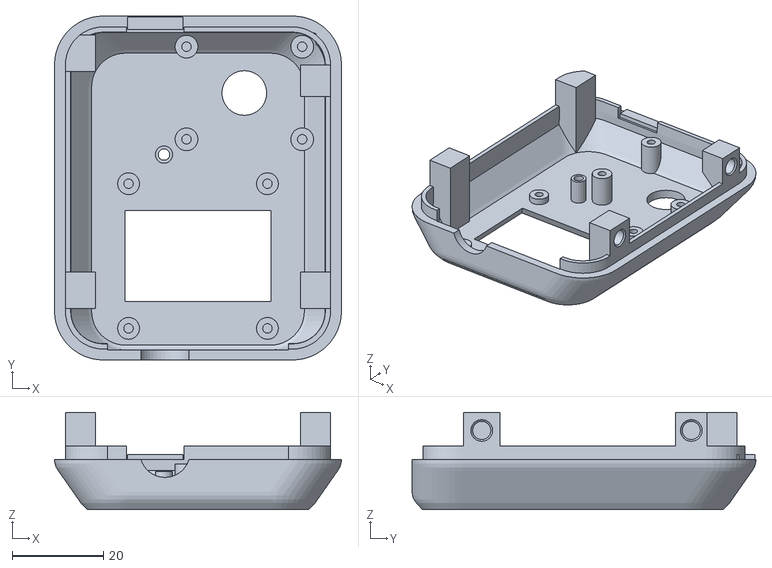
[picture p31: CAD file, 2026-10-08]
case/concepts/stl_b2/lid.stl
63.0 x 75.5 x 21.4

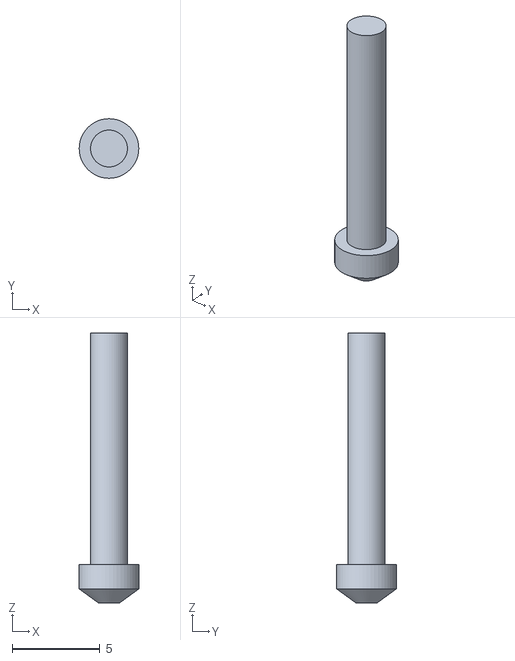
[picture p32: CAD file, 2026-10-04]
case/stl/plunger.stl
3.40 x 3.40 x 15.4

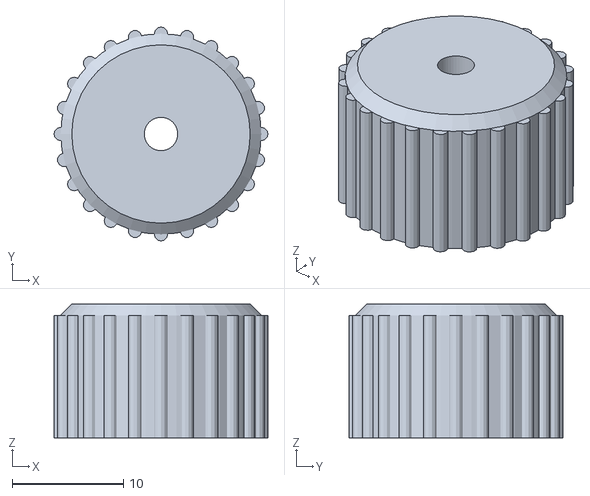
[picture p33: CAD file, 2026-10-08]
case/concepts/stl_b2/knob.stl
19.2 x 19.2 x 12.0

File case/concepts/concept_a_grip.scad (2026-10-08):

// =====================================================================
//  Concept A - "GRIP"   (concept-level massing model, not print-ready)
//
//  A slim two-zone handheld, the size of a SkyCaddie-style golf GPS.
//    * Handle (bottom): the 2 Ah pouch lies flat; the Twist sits directly on top of it,
//      so the dial lands under the thumb of the holding hand, in a shallow thumb pocket.
//    * Head (top): Thing Plus and GPS side by side (not stacked) under the OLED.
//      USB-C, microSD and the SMA port all on the top end.
//  The back is flat and prints flat; a separate TPU palm pad fills the palm, and the
//  TwistLock socket sits flush in the back of the head.
//
//  Frame: x = width, y = bottom (handle) -> top (antenna end), z = back -> front.
//  z = 0 is the inner floor. Ghost components are at their real SparkFun sizes.
//
//  part = "assembly" | "exploded" | "cutaway" | "cart" | "strap" | "chk" | "outer"
// =====================================================================
include <lib/components.scad>
include <lib/shape.scad>
include <lib/mount.scad>

part = "assembly";
pose = true;          // stand the model up for product-style renders
$fn = 40;

wall = 2.2;
rb = 4;   // back edge radius (with 45-degree printable lead-in)
rf = 8;   // front edge radius

// ---------- layout (inner coordinates) ----------
gps_x0  = 6.0;                                     // GPS kept 6 mm off the left wall so the head corner can be round
W_in    = gps_x0 + gps_w + 1.5 + tp_w + tp_keepout;  // 74.16; TP is rotated, so its plug side faces the right wall
xc      = W_in/2;
batt_x0 = xc - batt[0]/2;
batt_y0 = 5.5;                                     // leaves room for the rounded bottom corners
gap_cable = 3.5;                                   // battery lead + Qwiic run between the zones
tp_y_far  = batt_y0 + batt[1] + gap_cable;         // Thing Plus is rotated 180: USB end at the top
tp_y_usb  = tp_y_far + tp_l;
H_in    = tp_y_usb + tp_usb_overhang + 1.0;
tp_x0   = gps_x0 + gps_w + 1.5;
gps_y0  = H_in - 0.6 - gps_l;                      // SMA edge 0.6 from the top wall (as v0.1)

z_board = 5.5;                                     // TP + GPS bottom face (on floor bosses)
z_tw    = batt[2] + batt_swell + tw_pins + 0.4;    // Twist PCB bottom, pins clear the pouch
Z_in    = z_tw + twist_top;                        // encoder body touches the lid (18.4)
z_oled  = Z_in - oled_glass[2] - 1.6;              // OLED PCB bottom (glass against the lid)
zb = -wall;  zf = Z_in + wall;
z_split = zf - rf;                                 // shell / lid parting line

tw_c   = [xc, batt_y0 + batt[1] - 1 - tw_h/2];
oled_c = [33.0, 104];                              // nudged left so the RESET plunger clears the OLED
rst_p  = [tp_x0 + tp_w - tp_rst[0], tp_y_usb - tp_rst[1]];
usb_x  = tp_x0 + tp_w - tp_usb_x;
sd_x   = tp_x0 + tp_w - tp_sd_x;
sma_x  = gps_x0 + gps_sma_x;
sma_z  = z_board + gps_sma_z;
sw_y   = 84;  sw_z = z_board + 3.5;                // left wall, below the GPS
qt_c   = [xc, 104];
dish_d = 32; dish_h = 1.0;                         // thumb pocket: flat floor (bridged), 45-degree rim

// plan corners [x, y, outer plan radius]
Rh = 9 + wall;  Rb = 8 + wall;
hx0 = xc - (batt[0]/2 + 1.6);
corners = [
    [9, H_in - 9, Rh], [W_in - 9, H_in - 9, Rh],          // head top
    [9, 76, Rh],       [W_in - 9, 76, Rh],                // head shoulders
    [hx0 + 8, 8, Rb],  [W_in - hx0 - 8, 8, Rb]            // handle bottom
];

Wo = W_in + 2*wall; Ho = H_in + 2*wall; Do = zf - zb;
echo(str("CONCEPT A GRIP outer: ", Wo, " x ", Ho, " x ", Do, " mm (head width; handle ",
         W_in - 2*hx0 + 2*wall, " wide at the bottom; palm pad +", 3.5, ")"));

module body(t) pebble(t, corners, zb, zf, rb, rf);

// ---------- shell (back + lid in one piece for massing; split shown by colour) ----------
module apertures() {
    translate([oled_c[0], oled_c[1], Z_in]) window_cut(oled_window, wall);
    translate([tw_c[0], tw_c[1], zf - dish_h]) cylinder(d1 = dish_d - 2*dish_h, d2 = dish_d + 0.02, h = dish_h + 0.01, $fn = 96);
    translate([tw_c[0], tw_c[1], Z_in - 1]) cylinder(d = enc_hole_d, h = 10);
    translate([rst_p[0], rst_p[1], z_board + 4.2]) cylinder(d = 2.5, h = 30, $fn = 16);
    translate([rst_p[0], rst_p[1], zf - 0.6]) cylinder(d1 = 2.5, d2 = 4, h = 0.61, $fn = 16);
    // top end: USB-C, microSD, SMA
    translate([usb_x, H_in - 1, z_board + 1.6 + 1.6]) rotate([-90, 0, 0]) linear_extrude(wall + 6) rrect2(12.6, 7.0, 2.2);
    translate([sd_x, H_in - 1, z_board - 0.7]) rotate([-90, 0, 0]) linear_extrude(wall + 6) rrect2(12.4, 2.6, 0.6);
    translate([sma_x, H_in - 1, sma_z]) rotate([-90, 0, 0]) cylinder(d = 11, h = wall + 6);
    // left side: EN slide switch
    translate([-wall - 3, sw_y - sw_slot[0]/2, sw_z - sw_slot[1]/2]) cube([wall + 4, sw_slot[0], sw_slot[1]]);
    // back: TwistLock socket
    translate([qt_c[0], qt_c[1], zb]) qt_socket_cut();
    // bottom end: wrist-strap passage
    translate([xc, -wall, 4]) lanyard_cut();
}
module inner_features() {
    // TwistLock socket boss, lanyard block
    translate([qt_c[0], qt_c[1], zb]) qt_socket_boss();
    translate([xc - 8, -1, 0]) cube([16, batt_y0 - 0.5 + 1, 8]);
    // TP standoffs (2 holes at the USB end) + far-end rest, GPS standoffs
    for (h = [[2.54, 2.54], [20.32, 2.54]]) translate([tp_x0 + tp_w - h[0], tp_y_usb - h[1], -1]) cylinder(d = 5, h = z_board + 1);
    translate([tp_x0 + tp_w/2 - 5, tp_y_far + 1, -1]) cube([10, 3, z_board + 1]);
    for (h = gps_holes) translate([gps_x0 + h[0], gps_y0 + h[1], -1]) cylinder(d = 5, h = z_board + 1);
    // battery corner ribs
    for (sx = [0, 1], sy = [0, 1]) translate([batt_x0 - 1.2 + sx*(batt[0] + 1.4), batt_y0 - 1.2 + sy*(batt[1] + 1.4), -1]) cube([1.0, 1.0, 4]);
}
module lid_features() {
    // Twist hangs from lid bosses; OLED ears on short bosses
    for (sx = [-1, 1], sy = [-1, 1]) {
        translate([tw_c[0] + sx*tw_holes[0]/2, tw_c[1] + sy*tw_holes[1]/2, z_tw + 1.6]) cylinder(d = 5, h = Z_in - z_tw - 1.6 + 1);
        translate([oled_c[0] + sx*oled_holes[0]/2, oled_c[1] + sy*oled_holes[1]/2, z_oled + 1.6]) cylinder(d = 4.8, h = oled_glass[2] + 1);
    }
    // RESET guide tube
    translate([rst_p[0], rst_p[1], z_board + 1.6 + 2.5 + 2.6]) cylinder(d = rst_tube_od, h = 20, $fn = 20);
}
// back shell (z < z_split) and lid (z >= z_split, plus the bosses that hang below it)
module half(front) intersection() { difference() { body(0); body(wall); } translate([-50, -50, front ? z_split : zb - 10]) cube([200, 300, front ? 50 : z_split - zb + 10]); }
module back_shell() difference() { union() { half(false); intersection() { body(0.01); inner_features(); } } apertures(); }
module lid_shell()  difference() { union() { half(true);  intersection() { body(0.01); lid_features(); } } apertures(); }
module shell_solid() { back_shell(); lid_shell(); }

// palm pad: separate TPU part on the back of the handle (prints flat side down)
module palm_pad() color("#4a4a4a") translate([xc, 34, zb + 0.01]) intersection() {
    scale([24, 28, 3.5]) sphere(r = 1, $fn = 64);
    translate([-40, -40, -10]) cube([80, 80, 10]);
}

// ---------- components ----------
module place_tp()   translate([tp_x0 + tp_w, tp_y_usb, z_board]) rotate([0, 0, 180]) children();
module place_gps()  translate([gps_x0, gps_y0, z_board]) children();
module place_oled() translate([oled_c[0], oled_c[1], z_oled]) children();
module place_tw()   translate([tw_c[0], tw_c[1], z_tw]) children();
module place_batt() translate([batt_x0, batt_y0, 0]) children();
module place_sw()   translate([0, sw_y, sw_z]) children();

module comps_base() {
    place_tp() ghost_tp();
    place_gps() { ghost_gps(); ghost_sma_plug(); }
    place_batt() ghost_batt();
    place_sw() ghost_switch();
}
module comps_lid() {
    place_oled() ghost_oled();
    place_tw() ghost_twist();
    color("orange") translate([rst_p[0], rst_p[1], z_board + 1.6 + 2.5 + 0.1]) cylinder(d = rst_pin_d, h = zf + 1 - (z_board + 4.2), $fn = 16);
}
module dial_knob() translate([tw_c[0], tw_c[1], zf - dish_h + 0.6]) ghost_knob();
module keep_all() {
    place_tp() keep_tp();
    place_gps() keep_gps();
    place_oled() keep_oled();
    place_tw() keep_twist();
    place_batt() keep_batt();
    place_sw() translate([0, -sw_body[1]/2, -sw_body[2]/2]) cube(sw_body);
}
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

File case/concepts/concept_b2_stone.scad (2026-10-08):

// =====================================================================
//  Concept B2 - "STONE, LAYERED"   (print-ready: back shell, lid, plate, knob, plunger)
//
//  B's palm stone with a smaller footprint, bought with depth. Four layers, back -> front:
//    1. the 2 Ah pouch (on the floor, or on the TwistLock socket boss if mount_socket)
//    2. chassis plate + Thing Plus on the left (USB-C at the bottom end, plug keep-out
//       against the left wall)
//    3. split by zone, sharing the same depth instead of stacking:
//         top    : GPS (SMA edge 0.6 mm off the top wall) on three plate posts, OLED in front
//         bottom : the Twist on its own, dial lower right, hung from lid bosses (as v0.1)
//    4. lid
//  The Thing Plus RESET (28.2 mm from the USB end) gets a straight plunger path between
//  the Twist (to its right) and the GPS (above it).
//
//  Lens section: straight sides from the back up to a shoulder just above the boards, then
//  the sides lean 6 mm inward (40.6 deg) to a smaller face (left, right, bottom; not the top,
//  where the SMA sits). Plan corners limited by the pouch corners (8.5 mm inside radius).
//
//  Retention (differs from v0.1, see README "Printing B2"): the pouch fills the floor to
//  within 1.8 mm of the side walls, so v0.1's back-to-lid screw posts have nowhere to stand
//  and top tongues would hit the GPS. Instead four lid tabs drop inside the back shell; three
//  M3 x 8 countersunk screws go through the side walls into heat-set inserts in the tabs.
//  The same tabs clamp the plate down onto ledges; two M2.5 pan screws locate the plate.
//
//  Frame: x = width, y = bottom (USB end) -> top (antenna end), z = back -> front.
//  z = 0 is the inner floor. Ghost components are at their real SparkFun sizes.
//
//  part = views : "assembly" | "exploded" | "cutaway" | "side" | "cart" | "strap"
//         print : "back_shell" | "lid" | "plate" | "knob" | "plunger"   (print orientation)
//         checks: "chk" | "chk_out" | "chk_comp" | "chk_plate" | "chk_pilot" | "chk_cart"
// =====================================================================
include <lib/components.scad>
include <lib/shape.scad>
include <lib/mount.scad>
use <../cad/shot_tracker_case.scad>      // v0.1's knob() for the printed knob

part = "assembly";
pose = true;
mount_socket = false;   // TwistLock socket in the back. Off for the first print: thinner case.
batt_lift = 0.4;        // pouch height above the inner floor when there's no socket boss (clears the back edge radius)
show_hw = true;         // draw screws / inserts in the views
$fn = 40;

wall = 2.2;
rb   = mount_socket ? 6 : 3;  // back edge radius; tighter without the socket so the low pouch's corners clear it
Rc_in  = 8.5;                 // plan corner radius (inside), limited by the pouch corners

// ---------- print / fit tolerances and hardware (v0.1 values) ----------
lip_clr  = 0.2;  lip_t = 1.2;  lip_h = 3.0;
insert_d = 4.0;  insert_l = 5.8;  insert_od = 5.0;   // M3 heat-set insert (4.0 hole, <= 5.8 long)
m3_clear = 3.4;  m3_csk_d = 6.4;  m3_fh_k = 1.9;     // M3 x 8 flat head (ISO 10642)
m25_pilot = 2.1; m25_clear = 2.8;  m25_head = [4.5, 1.75];   // M2.5 pan head
skin_min = 0.6;                                       // pilot holes stop this far from any outer face

// ---------- z stack (inner floor = 0) ----------
zb      = -wall;
z_batt  = mount_socket ? zb + qt_depth + qt_floor + 0.2 : batt_lift;   // layer 1: pouch on the socket boss, or the floor
plate_t = 1.6;
z_plate = z_batt + batt[2] + batt_swell;            // layer 2: plate
z_ptop  = z_plate + plate_t;
z_board = z_ptop + tp_standoff;                     //          Thing Plus bottom
z_comp  = z_board + 1.6 + tp_parts_h;               //          Thing Plus tallest part
z_gps   = z_comp + 0.6;                             // layer 3 top: GPS bottom
z_gps_top = z_gps + 1.6 + 3.0;                      //          (J4 is the tallest part)
z_oled  = z_gps_top + oled_rear + 0.4;              //          OLED PCB bottom
Z_in    = z_oled + 1.6 + oled_glass[2];             // lid inner
zf      = Z_in + wall;
z_tw    = Z_in - twist_top;                         // layer 3 bottom: encoder body touches the lid (as v0.1)
btn_top = z_board + 1.6 + 2.5;                      // RESET tact switch top

// ---------- plan layout ----------
W_in    = batt[0] + 2*1.8;                          // pouch + corner margin
tp_x0   = 1.5 + tp_keepout;                         // plug keep-out against the left wall
tp_y0   = 1.0 + tp_usb_overhang;
rst_p   = [tp_x0 + tp_rst[0], tp_y0 + tp_rst[1]];
tw_c    = [rst_p[0] + 2.4 + tw_w/2, 2.0 + tw_h/2];  // Twist just right of the plunger, lid bosses clear of its tube
gps_y0  = rst_p[1] + rst_pin_d/2 + 0.6;             // GPS starts just above the plunger
H_in    = gps_y0 + gps_l + 0.6;                     // SMA edge 0.6 off the top wall (v0.1 value)
gps_x0  = W_in/2 - gps_w/2;
oled_c  = [W_in/2, gps_y0 + gps_l/2 + 0.3];
batt_x0 = W_in/2 - batt[0]/2;
batt_y0 = H_in/2 - batt[1]/2;
usb_x   = tp_x0 + tp_usb_x;
sd_x    = tp_x0 + tp_sd_x;
usb_z   = z_board + 1.6 + 1.6;
sma_x   = gps_x0 + gps_sma_x;
sma_z   = z_gps + gps_sma_z;
sw_y    = 45;  sw_z = z_board + 1.8;                // right wall, layer 2
qt_c    = [W_in/2, H_in/2];
z_tube  = z_gps_top + 0.4;                          // RESET guide tube starts above the GPS parts

// Lens section: full plan from the back up to a shoulder just above the layer-3 boards,
// then the sides lean in toward a smaller face (<= 45 deg, so the face-down lid prints
// without supports). No lean at the top: the SMA, J4 and the OLED's top ears sit there.
Rp     = Rc_in + wall;
z_sh   = z_comp + 3.0;      // shoulder (ring equator)
r_sh   = 4;                 // = rf, so the lean is one straight flank
rf     = 4;                 // face edge radius
lean   = [4.9, 4.9, 4.9, 0]; // face inset per side: left, right, bottom, top. 4.9 over a 7 mm rise = 35 deg on the sides
                            // and 44.7 deg on the diagonal at the bottom corners (6 would be 50.5 there: unprintable face-down)
// [x, y, plan radius, face-centre shift x, y]
corners = [[Rc_in, Rc_in, Rp,  lean[0],  lean[2]], [W_in - Rc_in, Rc_in, Rp, -lean[1],  lean[2]],
           [Rc_in, H_in - Rc_in, Rp, lean[0], -lean[3]], [W_in - Rc_in, H_in - Rc_in, Rp, -lean[1], -lean[3]]];
zs = z_sh;                  // shell / lid parting plane (the widest section)

// ---------- fastener positions ----------
// lid tabs: [x side (0 = left, 1 = right), y centre, y half-length, screwed]; inserts horizontal along x.
// The lower-left tab has no screw: a head there would sit on the bottom-left corner curve
// (up to 1 mm proud), and the Thing Plus plug keep-out blocks the straight wall above it.
// It still clamps the plate and locates the lid.
tab_z0   = z_ptop;                                  // tabs bear on the plate (clamp it to the ledges)
ins_z    = z_board + 1.6;                           // insert axis height (13.0 without the socket)
tab_w    = 6.8;                                     // tab depth from the wall
tabs     = [[0, 6, 4, false], [1, 12, 3.5, true], [0, 58, 4, true], [1, 58, 4, true]];   // screw heads on the straight part of the walls
screwed  = [for (t = tabs) if (t[3]) t];
tp_holes_w   = [for (h = [[2.54, 2.54], [20.32, 2.54]]) [tp_x0 + h[0], tp_y0 + h[1]]];
gps_holes_w  = [for (h = gps_holes) let (p = [gps_x0 + h[0], gps_y0 + h[1]])
                if (!(p[0] < tp_x0 + tp_w + 3 && p[1] < tp_y0 + tp_l + 3)) p];   // 3 posts; the 4th hole sits over the TP
tw_holes_w   = [for (sx = [-1, 1], sy = [-1, 1]) [tw_c[0] + sx*tw_holes[0]/2, tw_c[1] + sy*tw_holes[1]/2]];
oled_holes_w = [for (sx = [-1, 1], sy = [-1, 1]) [oled_c[0] + sx*oled_holes[0]/2, oled_c[1] + sy*oled_holes[1]/2]];
plate_scr    = [[33, 2.0], [30, H_in - 2.0]];        // plate -> bottom / top ledges
lan_x        = 45;                                   // wrist-strap passage, bottom end
ledge_d      = 3.2;                                  // bottom / top ledge depth (pouch is 3.55 from those walls)

// screw lengths (mm, under-head)
L_tp = 5; L_gps = 6; L_tw = 5; L_oled = 4; L_plate = 6; L_side = 8;   // L_tw: the lower Twist holes sit under the leaning flank

Wo = W_in + 2*wall; Ho = H_in + 2*wall; Do = zf - zb;
echo(str("CONCEPT B2 outer: ", Wo, " x ", Ho, " x ", Do, " mm (mount_socket = ", mount_socket, ")"));
echo(str("z: batt ", z_batt, "  plate ", z_plate, "  TP ", z_board, "  GPS ", z_gps, "  Twist ", z_tw,
         "  OLED ", z_oled, "  lid ", Z_in, "  face ", zf, "  split ", zs));
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

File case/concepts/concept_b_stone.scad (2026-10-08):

// =====================================================================
//  Concept B - "STONE"   (concept-level massing model, not print-ready)
//
//  A compact, soft palm-stone that keeps v0.1's proven stack (battery on the floor,
//  chassis plate above it, boards on the plate, OLED under the lid) but rearranges
//  the front so it gets thinner and easier on the thumb:
//    * The Twist moves off the boards into the free plate corner beside the GPS
//      (bottom-right), on short plate standoffs. It no longer stacks on top of the
//      Thing Plus, so the case loses ~2 mm of depth even after adding the mount socket,
//      and the dial sits where a right thumb naturally rests.
//    * The knob sits in a dial cup (recessed well), so it's lower and protected.
//    * Big front radius, 45-degree printable lead-in on both faces.
//  The TwistLock socket is flush in the centre of the back.
//
//  Frame: x = width, y = bottom (USB end) -> top (antenna end), z = back -> front.
//  z = 0 is the inner floor. Ghost components are at their real SparkFun sizes.
//
//  part = "assembly" | "exploded" | "cutaway" | "cart" | "strap" | "chk" | "chk_out" | "chk_cart"
// =====================================================================
include <lib/components.scad>
include <lib/shape.scad>
include <lib/mount.scad>

part = "assembly";
pose = true;
$fn = 40;

wall = 2.2;
rb = 6;   rf = 10;   crown = 0;    // a crowned face would not sit flat for the face-down lid print

// ---------- layout (inner coordinates) ----------
W_in = 75;  H_in = 76;
tp_x0 = 2 + tp_keepout;                  // TP not rotated: USB at the bottom, plug side faces the left wall
tp_y0 = 1.0 + tp_usb_overhang;           // USB-end board edge
gps_x0 = tp_x0 + tp_w + 1.5;
gps_y0 = H_in - 2.2 - gps_l;             // SMA edge 2.2 off the top wall (lets the top-right corner be round)
batt_x0 = W_in/2 - batt[0]/2;
batt_y0 = H_in/2 - batt[1]/2;

zb = -wall;
z_batt  = zb + qt_depth + qt_floor + 0.2;            // pouch rests on the socket boss / ribs
plate_t = 1.6;
z_plate = z_batt + batt[2] + batt_swell;             // plate bottom
z_board = z_plate + plate_t + tp_standoff;           // TP + GPS bottom
z_comp  = z_board + 1.6 + tp_parts_h;
z_oled  = z_comp + oled_rear + 0.4;                  // OLED PCB bottom
Z_in    = z_oled + 1.6 + oled_glass[2];              // lid inner (glass against it)
zf      = Z_in + wall;
z_split = zf - rf;
well_d  = 3.0;                                       // dial cup depth
z_well  = zf - well_d;                               // cup floor (top face)
z_tw    = z_well - 1.6 - 0.2 - twist_top;            // Twist PCB bottom: encoder just under the cup floor

tw_c   = [(tp_x0 + tp_w + W_in)/2, 4 + tw_h/2];
oled_c = [34, 53];
rst_p  = [tp_x0 + tp_rst[0], tp_y0 + tp_rst[1]];
usb_x  = tp_x0 + tp_usb_x;
sd_x   = tp_x0 + tp_sd_x;
sma_x  = gps_x0 + gps_sma_x;
sma_z  = z_board + gps_sma_z;
sw_y   = 50;  sw_z = z_board + 1.8;                  // right wall, beside the GPS
qt_c   = [W_in/2, H_in/2];

Rc = 11 + wall;
corners = [[11, 11, Rc], [W_in - 11, 11, Rc], [11, H_in - 11, Rc], [W_in - 11, H_in - 11, Rc]];

Wo = W_in + 2*wall; Ho = H_in + 2*wall; Do = zf + crown - zb;
echo(str("CONCEPT B STONE outer: ", Wo, " x ", Ho, " x ", Do, " mm"));
echo(str("z: batt ", z_batt, "  plate ", z_plate, "  boards ", z_board, "  twist ", z_tw, "  oled ", z_oled, "  lid ", Z_in));

module body(t) hull() {
    pebble(t, corners, zb, zf, rb, rf);
    if (crown > 0) translate([W_in/2, H_in/2 + 3, zf + crown - t - 0.01]) cylinder(r = 24, h = 0.01, $fn = 64);   // optional crowned face (needs supports face-down)
}

// ---------- shell ----------
module apertures() {
    translate([oled_c[0], oled_c[1], Z_in]) window_cut(oled_window, wall + crown + 0.5);
    // dial cup + encoder hole
    translate([tw_c[0], tw_c[1], z_well]) cylinder(d1 = 22, d2 = 22 + 2*(zf + 1 - z_well), h = zf + 1 - z_well, $fn = 64);   // 45-degree wall, prints face-down
    translate([tw_c[0], tw_c[1], z_well - 3]) cylinder(d = enc_hole_d, h = 10);
    translate([rst_p[0], rst_p[1], z_board + 4.2]) cylinder(d = 2.5, h = 30, $fn = 16);
    // bottom end: USB-C + microSD
    translate([usb_x, 1, z_board + 1.6 + 1.6]) rotate([90, 0, 0]) linear_extrude(wall + 6) rrect2(12.6, 7.0, 2.2);
    translate([sd_x, 1, z_board - 0.7]) rotate([90, 0, 0]) linear_extrude(wall + 6) rrect2(12.4, 2.6, 0.6);
    // top end: SMA
    translate([sma_x, H_in - 1, sma_z]) rotate([-90, 0, 0]) cylinder(d = 11, h = wall + 6);
    // right side: EN switch
    translate([W_in - 1, sw_y - sw_slot[0]/2, sw_z - sw_slot[1]/2]) cube([wall + 4, sw_slot[0], sw_slot[1]]);
    // back: TwistLock socket
    translate([qt_c[0], qt_c[1], zb]) qt_socket_cut();
    // left side: wrist-strap passage
    translate([-wall, 62, 4.5]) rotate([0, 0, -90]) lanyard_cut();
}
plate_pillars = [[4.5, 26], [4.5, 58], [70.5, 22], [70.5, 62]];
module inner_features() {
    translate([qt_c[0], qt_c[1], zb]) qt_socket_boss();
    translate([-1, 56, -1]) cube([9, 12, 10]);                                     // lanyard block
    for (p = plate_pillars) translate([p[0], p[1], -1]) cylinder(d = 5.4, h = z_plate + 1);
    for (sx = [0, 1], sy = [0, 1]) translate([batt_x0 - 1.2 + sx*(batt[0] + 1.4), batt_y0 - 1.2 + sy*(batt[1] + 1.4), -1]) cube([1.0, 1.0, z_batt + 4]);
    for (x = [batt_x0 + 8, batt_x0 + batt[0] - 8]) translate([x - 0.6, batt_y0 + 4, -1]) cube([1.2, batt[1] - 8, z_batt + 1]);   // pouch support ribs
}
module lid_features() {
    // dial cup wall
    translate([tw_c[0], tw_c[1], z_well - 1.6]) cylinder(d = 34, h = Z_in - z_well + 1.6 + 1, $fn = 64);
    for (sx = [-1, 1], sy = [-1, 1])
        translate([oled_c[0] + sx*oled_holes[0]/2, oled_c[1] + sy*oled_holes[1]/2, z_oled + 1.6]) cylinder(d = 4.8, h = oled_glass[2] + 1);
    translate([rst_p[0], rst_p[1], z_board + 1.6 + 2.5 + 2.6]) cylinder(d = rst_tube_od, h = 20, $fn = 20);
}
module half(front) intersection() { difference() { body(0); body(wall); } translate([-50, -50, front ? z_split : zb - 10]) cube([200, 200, front ? 50 : z_split - zb + 10]); }
module back_shell() difference() { union() { half(false); intersection() { body(0.01); inner_features(); } } apertures(); }
module lid_shell()  difference() { union() { half(true);  intersection() { body(0.01); lid_features(); } } apertures(); }
module shell_solid() { back_shell(); lid_shell(); }
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

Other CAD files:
case/stl/knob.stl
case/concepts/lineup.scad
case/cad/shot_tracker_case.scad
case/concepts/mount_kit.scad

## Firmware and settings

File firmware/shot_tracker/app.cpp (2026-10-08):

// =====================================================================
//  Golf Shot Tracker firmware - v0.1
//  SparkFun Thing Plus ESP32-S3 + NEO-M9N GPS + Qwiic OLED 1.3" + Qwiic Twist
//
//  Dial:  turn = choose club / move in menus
//         click = select / mark position
//         hold  = open menu (hold again or pick "Back" to close)
//  Shot:  pick club -> click at the ball (start marked) -> walk to the ball ->
//         click (landing marked, distance shown). Putter = one click, no landing.
//         "Hole out" (last slot on the dial, after the putter) finishes the hole.
//  USB serial (115200): type "help" for export commands.
// =====================================================================
#include <Arduino.h>
#include <Wire.h>
#include <esp_sleep.h>
#include <driver/gpio.h>
#include <time.h>
#include <SparkFun_MAX1704x_Fuel_Gauge_Arduino_Library.h>

#include "config.h"
#include "model.h"
#include "storage.h"
#include "gps.h"
#include "input.h"
#include "ui.h"

// ---------------------------------------------------------------------------
// globals
// ---------------------------------------------------------------------------
Ui ui;
Gps gps;
Input input;
SFE_MAX1704X fuel(MAX1704X_MAX17048);
bool fuelOk = false;
int batteryPct = -1;
bool charging = false;

static Round round_;      // the round in progress (~9 KB)
static Round scratch_;    // used by serial export

enum class Scr : uint8_t { Home, Club, Mark, Flight, Result, Menu, Holes, Confirm, Score, GpsInfo };
Scr scr = Scr::Home;

enum class MarkFor : uint8_t { Start, End };
MarkFor markFor = MarkFor::Start;

enum Action : uint8_t {
  A_NONE, A_BACK, A_NEW_ROUND, A_NEXT_HOLE, A_GOTO_HOLE, A_UNDO, A_SCORECARD, A_GPS,
  A_END_ROUND, A_POWER_OFF, A_ROUNDS_INFO, A_RETRY_MARK, A_SAVE_NO_GPS, A_CANCEL_MARK,
  A_FINISH_ROUND, A_PICK_ROUND, A_DELETE_ROUND, A_HOME,
};

uint8_t dialSel = 0;         // 0..NUM_CLUBS-1 = club, NUM_CLUBS = "Hole out"
int lastResult = -1;
uint32_t resultAt = 0;
uint8_t holeSel = 1;

// generic list menu (also used for Home and the mark-failed prompt)
struct MenuItem { char label[22]; Action act; uint32_t arg; };
MenuItem menu[10];
const char* menuLabels[10];
uint8_t menuCount = 0, menuSel = 0;
char menuTitle[22] = "";
Scr menuBack = Scr::Club;    // where long-press / "Back" returns to

// yes/no confirm
Action confirmAct = A_NONE;
uint32_t confirmArg = 0;
char confirmTitle[22] = "";
char confirmLine[22] = "";
uint8_t confirmSel = 0;      // 0 = No (default), 1 = Yes
Scr confirmBack = Scr::Menu;

char toast[22] = "";
uint32_t toastUntil = 0;
bool dirty = true;

// ---------------------------------------------------------------------------
// helpers
// ---------------------------------------------------------------------------
uint8_t putterIndex() {
  for (uint8_t i = 0; i < NUM_CLUBS; i++) if (!strcmp(CLUBS[i], PUTTER_NAME)) return i;
  return NUM_CLUBS - 1;
}
bool isPutter(uint8_t club) { return club == putterIndex(); }

void go(Scr s) { scr = s; dirty = true; }
void showToast(const char* msg, uint32_t ms = 2000) {
  strlcpy(toast, msg, sizeof toast);
  toastUntil = millis() + ms;
  dirty = true;
}
void saveRound() {
  if (!storage::save(round_)) showToast("SAVE FAILED!", 4000);
}
Scr roundHome() { return round_.inFlight() ? Scr::Flight : Scr::Club; }

void menuReset(const char* title, Scr back) {
  strlcpy(menuTitle, title, sizeof menuTitle);
  menuCount = 0; menuSel = 0; menuBack = back;
}
void menuAdd(const char* label, Action a, uint32_t arg = 0) {
  if (menuCount >= 10) return;
  strlcpy(menu[menuCount].label, label, sizeof menu[0].label);
  menu[menuCount].act = a;
  menu[menuCount].arg = arg;
  menuLabels[menuCount] = menu[menuCount].label;
  menuCount++;
}
void confirm(const char* title, const char* line, Action a, Scr back, uint32_t arg = 0) {
  strlcpy(confirmTitle, title, sizeof confirmTitle);
  strlcpy(confirmLine, line, sizeof confirmLine);
  confirmAct = a; confirmArg = arg; confirmSel = 0; confirmBack = back;
  go(Scr::Confirm);
}

// Home and the rounds list share the menu buffer, so going "back" to Home rebuilds it.
void openHome();
void menuGoBack() { if (menuBack == Scr::Home) openHome(); else go(menuBack); }

// ---------------------------------------------------------------------------
// menus
// ---------------------------------------------------------------------------
// Fills ids[] with saved round ids, newest first. Returns how many were found (may exceed max).
int listRoundIds(uint32_t* ids, int max) {
  int n = 0;
  File dir = LittleFS.open("/rounds");
  for (File f = dir.openNextFile(); f; f = dir.openNextFile()) {
    String name = f.name();
    int slash = name.lastIndexOf('/');
    if (slash >= 0) name = name.substring(slash + 1);
    if (!name.endsWith(".bin")) continue;
    uint32_t id = name.toInt();
    // insertion sort, keeping the newest `max`
    int i = min(n, max);
    while (i > 0 && ids[i - 1] < id) { if (i < max) ids[i] = ids[i - 1]; i--; }
    if (i < max) ids[i] = id;
    n++;
  }
  return n;
}
int countRounds() { uint32_t none[1]; return listRoundIds(none, 0); }

// "Oct 2" from the round's start time, or "" when GPS time wasn't known.
void roundDate(const Round& r, char* buf, size_t n) {
  buf[0] = 0;
  if (!r.h.startUnix) return;
  static const char* const MON[] = {"Jan","Feb","Mar","Apr","May","Jun","Jul","Aug","Sep","Oct","Nov","Dec"};
  time_t t = r.h.startUnix;
  struct tm tm;
  gmtime_r(&t, &tm);
  snprintf(buf, n, "%s %d", MON[tm.tm_mon % 12], tm.tm_mday);
}

void openRounds() {
  uint32_t ids[9];
  int total = listRoundIds(ids, 9);
  menuReset(total > 9 ? "ROUNDS (newest 9)" : "ROUNDS", Scr::Home);
  menuAdd("Back", A_HOME);
  for (int i = 0; i < min(total, 9); i++) {
    char date[8], buf[22];
    if (!storage::load(ids[i], scratch_)) {
      snprintf(buf, sizeof buf, "#%lu (unreadable)", (unsigned long)ids[i]);
    } else {
      roundDate(scratch_, date, sizeof date);
      snprintf(buf, sizeof buf, "#%lu %s %u sh%s", (unsigned long)ids[i], date, scratch_.totalStrokes(),
               scratch_.h.finished ? "" : "*");
    }
    menuAdd(buf, A_PICK_ROUND, ids[i]);
  }
  go(Scr::Menu);
}

void openHome() {
  menuReset("SHOT TRACKER", Scr::Home);
  menuAdd("New round", A_NEW_ROUND);
  char buf[22];
  snprintf(buf, sizeof buf, "Saved rounds (%d)", countRounds());
  menuAdd(buf, A_ROUNDS_INFO);
  menuAdd("GPS status", A_GPS);
  menuAdd("Power off", A_POWER_OFF);
  go(Scr::Home);
}

void openRoundMenu() {
  menuReset("MENU", roundHome());
  menuAdd("Back", A_BACK);
  menuAdd("Next hole", A_NEXT_HOLE);
  menuAdd("Go to hole...", A_GOTO_HOLE);
  if (round_.h.shotCount) menuAdd(round_.inFlight() ? "Cancel this shot" : "Undo last shot", A_UNDO);
  menuAdd("Scorecard", A_SCORECARD);
  menuAdd("GPS status", A_GPS);
  menuAdd("End round", A_END_ROUND);
  menuAdd("Power off", A_POWER_OFF);
  go(Scr::Menu);
}

void openMarkFailed() {
  menuReset("NO GPS FIX", roundHome());
  menuAdd("Try again", A_RETRY_MARK);
  menuAdd("Save without GPS", A_SAVE_NO_GPS);
  menuAdd("Cancel", A_CANCEL_MARK);
  go(Scr::Menu);
}

// ---------------------------------------------------------------------------
// round logic
// ---------------------------------------------------------------------------
void newRound() {
  round_.reset();
  round_.h.id = storage::allocateId();
  round_.h.startUnix = gps.fix().unix;
  round_.h.currentHole = 1;
  saveRound();
  dialSel = 0;
  lastResult = -1;
  go(Scr::Club);
}

void finishRound() {
  round_.h.finished = 1;
  saveRound();
  char buf[22];
  snprintf(buf, sizeof buf, "Round %lu: %u shots", (unsigned long)round_.h.id, round_.totalStrokes());
  round_.reset();
  openHome();
  showToast(buf, 4000);
}

void gotoHole(uint8_t hole) {
  round_.h.currentHole = hole;
  saveRound();
  dialSel = round_.strokesOnHole(hole) ? dialSel : 0;
  go(Scr::Club);
}

void holeOut() {
  uint8_t h = round_.h.currentHole;
  char buf[22];
  uint8_t n = round_.strokesOnHole(h);
  snprintf(buf, sizeof buf, "Hole %u: %u stroke%s", h, n, n == 1 ? "" : "s");
  if (h >= NUM_HOLES) {
    confirm("ROUND COMPLETE?", buf, A_FINISH_ROUND, Scr::Club);
    return;
  }
  gotoHole(h + 1);
  showToast(buf, 3000);
}

void beginMark(MarkFor f) {
  markFor = f;
  gps.startMark();
  go(Scr::Mark);
}

void applyMark(const GeoPoint& p) {
  if (markFor == MarkFor::Start) {
    if (round_.h.shotCount >= MAX_SHOTS) { showToast("Shot limit reached"); go(Scr::Club); return; }
    Shot& s = round_.shots[round_.h.shotCount++];
    s = Shot();
    s.hole = round_.h.currentHole;
    s.club = dialSel;
    s.start = p;
    if (isPutter(dialSel)) s.flags |= SHOT_PUTT;
    saveRound();
    if (s.flags & SHOT_PUTT) {
      char buf[32];
      snprintf(buf, sizeof buf, "Putt #%u saved", round_.strokesOnHole(s.hole));
      showToast(buf);
      go(Scr::Club);
    } else {
      go(Scr::Flight);
    }
  } else {
    Shot* s = round_.last();
    if (!s) { go(Scr::Club); return; }
    s->end = p;
    s->flags |= SHOT_HAS_END;
    saveRound();
    lastResult = shotDistance(*s);
    resultAt = millis();
    go(Scr::Result);
  }
}

void undoLast() {
  Shot* s = round_.last();
  if (!s) return;
  bool wasFlight = round_.inFlight();
  dialSel = s->club;
  round_.h.currentHole = s->hole;
  round_.h.shotCount--;
  saveRound();
  showToast(wasFlight ? "Shot cancelled" : "Last shot deleted");
  go(Scr::Club);
}

[[noreturn]] void powerOff() {
  if (round_.active()) saveRound();
  ui.clear(); ui.medium();
  ui.center(10, "Power off");
  ui.small();
  ui.center(34, round_.active() ? "Round saved." : "");
  ui.center(46, "Press RESET to wake");
  ui.show();
  delay(1500);
  input.setColor(0, 0, 0);
  ui.power(false);
  // Cut the Qwiic rail (GPS, OLED, Twist) and hold it low through deep sleep.
  // Tip: cut jumper JP2 on the Thing Plus so the rail defaults OFF and this
  // pin isn't fighting its 10k pull-up (~330 uA) all night.
  digitalWrite(PIN_QWIIC_EN, LOW);
  // The gauge runs off the cell, so put back its default hibernate thresholds
  // (sample every 45 s instead of 250 ms) while we're off.
  if (fuelOk) { fuel.setHIBRTHibThr((uint8_t)0x80); fuel.setHIBRTActThr((uint8_t)0x30); }
  gpio_hold_en((gpio_num_t)PIN_QWIIC_EN);
  gpio_deep_sleep_hold_en();
  esp_sleep_disable_wakeup_source(ESP_SLEEP_WAKEUP_ALL);  // only RESET (or the EN switch) wakes us
  esp_deep_sleep_start();
  while (true) {}
}

void doAction(Action a) {
  switch (a) {
    case A_BACK: menuGoBack(); break;
    case A_HOME: openHome(); break;
    case A_NEW_ROUND: newRound(); break;
    case A_NEXT_HOLE:
      if (round_.h.currentHole >= NUM_HOLES) holeOut(); else gotoHole(round_.h.currentHole + 1);
      break;
    case A_GOTO_HOLE: holeSel = round_.h.currentHole; go(Scr::Holes); break;
    case A_UNDO:
      confirm(round_.inFlight() ? "CANCEL SHOT?" : "DELETE LAST SHOT?",
              CLUBS[round_.last()->club % NUM_CLUBS], A_UNDO, Scr::Menu);
      break;
    case A_SCORECARD: go(Scr::Score); break;
    case A_GPS: go(Scr::GpsInfo); break;
    case A_END_ROUND: confirm("END ROUND?", "Round will be saved", A_END_ROUND, Scr::Menu); break;
    case A_POWER_OFF: powerOff(); break;
    case A_ROUNDS_INFO:
      if (countRounds()) openRounds(); else showToast("No saved rounds");
      break;
    case A_PICK_ROUND: {
      uint32_t id = menu[menuSel].arg;
      char title[22], line[22], date[8] = "";
      snprintf(title, sizeof title, "DELETE ROUND #%lu?", (unsigned long)id);
      if (storage::load(id, scratch_)) {
        roundDate(scratch_, date, sizeof date);
        snprintf(line, sizeof line, "%s%s%u shots", date, date[0] ? ", " : "", scratch_.totalStrokes());
      } else {
        strlcpy(line, "unreadable round", sizeof line);
      }
      confirm(title, line, A_DELETE_ROUND, Scr::Menu, id);
      break;
    }
    case A_RETRY_MARK: beginMark(markFor); break;
    case A_SAVE_NO_GPS: applyMark(GeoPoint()); break;
    case A_CANCEL_MARK: go(roundHome()); break;
    default: break;
  }
}

void doConfirmed(Action a) {
  switch (a) {
    case A_UNDO: undoLast(); break;
    case A_END_ROUND: finishRound(); break;
    case A_FINISH_ROUND: finishRound(); break;
    case A_DELETE_ROUND: {
      char buf[22];
      bool ok = storage::removeRound(confirmArg);
      snprintf(buf, sizeof buf, ok ? "Round #%lu deleted" : "Delete failed", (unsigned long)confirmArg);
      if (countRounds()) openRounds(); else openHome();
      showToast(buf);
      break;
    }
    default: break;
  }
}

// ---------------------------------------------------------------------------
// input handling per screen
// ---------------------------------------------------------------------------
void handle(const InputEvents& e) {
  if (!e.any()) return;
  dirty = true;
  switch (scr) {
    case Scr::Home:
    case Scr::Menu:
      if (e.turn) menuSel = (uint8_t)constrain((int)menuSel + e.turn, 0, menuCount - 1);
      if (e.click) doAction(menu[menuSel].act);
      else if (e.longPress && scr == Scr::Menu) menuGoBack();
      break;

    case Scr::Club:
      if (e.turn) dialSel = (uint8_t)(((int)dialSel + e.turn % (NUM_CLUBS + 1) + NUM_CLUBS + 1) % (NUM_CLUBS + 1));
      if (e.click) { if (dialSel == DIAL_HOLE_OUT) holeOut(); else beginMark(MarkFor::Start); }
      if (e.longPress) openRoundMenu();
      break;

    case Scr::Mark:
      if (e.longPress) { gps.cancelMark(); go(roundHome()); showToast("Cancelled"); }
      break;

    case Scr::Flight:
      if (e.click) beginMark(MarkFor::End);
      if (e.longPress) openRoundMenu();
      break;

    case Scr::Result:
      if (e.longPress) openRoundMenu(); else go(Scr::Club);
      break;

    case Scr::Holes:
      if (e.turn) holeSel = (uint8_t)(((int)holeSel - 1 + e.turn % NUM_HOLES + NUM_HOLES) % NUM_HOLES + 1);
      if (e.click) gotoHole(holeSel);
      if (e.longPress) go(Scr::Menu);
      break;

    case Scr::Confirm:
      if (e.turn) confirmSel = e.turn > 0 ? 1 : 0;
      if (e.click) { if (confirmSel) doConfirmed(confirmAct); else go(confirmBack); }
      if (e.longPress) go(confirmBack);
      break;

    case Scr::Score:
    case Scr::GpsInfo:
      if (e.click || e.longPress) go(round_.active() ? Scr::Menu : Scr::Home);
      break;
  }
}

// ---------------------------------------------------------------------------
// drawing
// ---------------------------------------------------------------------------
// ---- icons (pixel art, '#' = lit) ----
static const char* const ICON_PIN[] = {   // GPS, 5x7
  ".###.",
  "#...#",
  "#.#.#",
  "#...#",
  ".#.#.",
  "..#..",
  "..#..",
};
static const char* const ICON_BOLT[] = {  // charging, 4x7
  "..##",
  ".##.",
  ".#..",
  "####",
  "..#.",
  ".##.",
  "##..",
};
static const char* const ICON_FLAG_SMALL[] = {  // home title, 7x8
  ".##....",
  ".####..",
  ".######",
  ".####..",
  ".##....",
  ".#.....",
  ".#.....",
  "###....",
};
static const char* const ICON_FLAG[] = {  // "Hole out" on the dial, 11x16
  ".##........",
  ".####......",
  ".######....",
  ".########..",
  ".##########",
  ".########..",
  ".######....",
  ".####......",
  ".##........",
  ".#.........",
  ".#.........",
  ".#.........",
  ".#.........",
  ".#.........",
  "####.......",
  "#####......",
};

// Header: title on the left; GPS pin + satellite count and a battery gauge on the right.
void drawHeader(const char* left) {
  ui.small();
  ui.text(0, 0, left);
  int x = Ui::W;
  if (batteryPct >= 0) {
    x -= 12;
    ui.battery(x, 1, batteryPct);
    if (charging) { x -= 6; ui.art(x, 1, ICON_BOLT, 7); }
    x -= 4;
  }
  char r[8];
  const Gps::Fix& f = gps.fix();
  bool blinkOn = (millis() / 500) % 2;
  if (!gps.present()) strcpy(r, "x");
  else if (gps.hasFix()) snprintf(r, sizeof r, "%u", f.siv);
  else strcpy(r, "?");
  x -= ui.width(r);
  ui.text(x, 0, r);
  x -= 7;
  if (gps.hasFix() || blinkOn) ui.art(x, 0, ICON_PIN, 7);   // pin blinks while searching
  ui.hline(9);
}

void drawFooter(const char* s) {
  ui.small();
  if (millis() < toastUntil) { ui.fill(0, 54, Ui::W, 10); ui.text((Ui::W - ui.width(toast)) / 2, 55, toast, true); }
  else ui.center(56, s);
}

void roundLabel(char* buf, size_t n) {
  uint8_t h = round_.h.currentHole;
  snprintf(buf, n, "H%u Shot %u", h, round_.strokesOnHole(h) + (round_.inFlight() ? 0 : 1));
}

void drawBigDistance(int d, int y) {
  char num[16];
  if (d < 0) strcpy(num, "--"); else snprintf(num, sizeof num, "%d", d);
  int w = Ui::bigWidth(num);
  ui.small();
  int x = (Ui::W - w - 3 - ui.width(unitLabel())) / 2;
  ui.bigText(x, y, num);
  ui.text(x + w + 3, y + Ui::DIG_H - 7, unitLabel());
}

void render() {
  char buf[32];
  ui.clear();
  switch (scr) {
    case Scr::Home:
    case Scr::Menu:
      if (scr == Scr::Home) ui.list(menuTitle, menuLabels, menuCount, menuSel, ICON_FLAG_SMALL, 7, 8);
      else ui.list(menuTitle, menuLabels, menuCount, menuSel);
      if (millis() < toastUntil) drawFooter("");
      break;

    case Scr::Club: {
      roundLabel(buf, sizeof buf);
      drawHeader(buf);
      ui.medium();
      const char* name = dialSel == DIAL_HOLE_OUT ? "Hole out" : CLUBS[dialSel];
      ui.center(20, name);
      if (dialSel == DIAL_HOLE_OUT) ui.art((Ui::W - ui.width(name)) / 2 - 15, 20, ICON_FLAG, 16);
      ui.text(0, 20, "<");
      ui.right(20, ">");
      const Shot* s = round_.last();
      if (dialSel == DIAL_HOLE_OUT) snprintf(buf, sizeof buf, "click: finish hole %u", round_.h.currentHole);
      else if (s && lastResult >= 0 && !(s->flags & SHOT_PUTT)) snprintf(buf, sizeof buf, "last: %s %d%s", CLUBS[s->club % NUM_CLUBS], lastResult, USE_YARDS ? "y" : "m");
      else snprintf(buf, sizeof buf, "click at the ball");
      ui.small();
      ui.center(42, buf);
      snprintf(buf, sizeof buf, "total %u   hold=menu", round_.totalStrokes());
      drawFooter(buf);
      break;
    }

    case Scr::Mark:
      drawHeader(markFor == MarkFor::Start ? "Marking shot" : "Marking ball");
      ui.medium();
      ui.center(18, "Hold still");
      ui.small();
      snprintf(buf, sizeof buf, gps.hasFix() ? "%u sats  +/-%.1fm" : "waiting for fix...", gps.fix().siv, gps.fix().hacc_mm / 1000.0f);
      ui.center(40, buf);
      ui.progress(gps.markProgress());
      break;

    case Scr::Flight: {
      const Shot* s = round_.last();
      snprintf(buf, sizeof buf, "H%u %s", round_.h.currentHole, s ? CLUBS[s->club % NUM_CLUBS] : "");
      drawHeader(buf);
      int d = -1;
      if (s && s->start.valid && gps.hasFix())
        d = (int)lround(toDisplayUnits(distanceMeters(s->start.lat_e7, s->start.lon_e7, gps.fix().lat_e7, gps.fix().lon_e7)));
      drawBigDistance(d, 14);
      drawFooter("click at your ball");
      break;
    }

    case Scr::Result: {
      const Shot* s = round_.last();
      drawHeader(s ? CLUBS[s->club % NUM_CLUBS] : "");
      drawBigDistance(lastResult, 14);
      drawFooter(lastResult < 0 ? "saved (no GPS)" : "shot saved");
      break;
    }

    case Scr::Holes:
      drawHeader("Go to hole");
      snprintf(buf, sizeof buf, "%u", holeSel);
      ui.bigText((Ui::W - Ui::bigWidth(buf)) / 2, 14, buf);
      snprintf(buf, sizeof buf, "%u strokes so far", round_.strokesOnHole(holeSel));
      drawFooter(buf);
      break;

    case Scr::Confirm:
      ui.small();
      ui.center(0, confirmTitle);
      ui.hline(9);
      ui.small();
      ui.center(16, confirmLine);
      ui.medium();
      if (confirmSel == 0) { ui.fill(10, 34, 48, 18); ui.text(18, 35, "No", true); ui.text(80, 35, "Yes"); }
      else { ui.fill(70, 34, 48, 18); ui.text(18, 35, "No"); ui.text(80, 35, "Yes", true); }
      break;

    case Scr::Score: {
      drawHeader("Scorecard");
      ui.small();
      unsigned out = 0, in = 0;
      for (uint8_t h = 1; h <= NUM_HOLES; h++) {
        uint8_t n = round_.strokesOnHole(h);
        (h <= 9 ? out : in) += n;
        int col = (h - 1) % 9, x = 2 + col * 14;
        int y = h <= 9 ? 12 : 32;
        snprintf(buf, sizeof buf, "%u", h);
        ui.text(x, y, buf);
        if (n) snprintf(buf, sizeof buf, "%u", n); else strcpy(buf, "-");
        if (h == round_.h.currentHole) ui.fill(x - 1, y + 8, 12, 9);
        ui.text(x, y + 9, buf, h == round_.h.currentHole);
      }
      snprintf(buf, sizeof buf, "Out %u  In %u  Tot %u", out, in, out + in);
      ui.center(55, buf);
      break;
    }

    case Scr::GpsInfo: {
      drawHeader("GPS status");
      const Gps::Fix& f = gps.fix();
      ui.small();
      if (!gps.present()) { ui.center(24, "GPS not detected"); ui.center(34, "check Qwiic cable"); break; }
      snprintf(buf, sizeof buf, "fix %u  sats %u  %s", f.fixType, f.siv, gps.hasFix() ? "OK" : "--");
      ui.text(0, 13, buf);
      snprintf(buf, sizeof buf, "acc +/- %.1f m", f.hacc_mm / 1000.0f);
      ui.text(0, 23, buf);
      snprintf(buf, sizeof buf, "lat %.6f", f.lat_e7 / 1e7);
      ui.text(0, 33, buf);
      snprintf(buf, sizeof buf, "lon %.6f", f.lon_e7 / 1e7);
      ui.text(0, 43, buf);
      ui.center(56, "click to close");
      break;
    }
  }
  ui.show();
}
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
void loop() {
  static uint32_t lastRender = 0, lastFuel = 0;
  uint32_t now = millis();

  gps.poll();
  handle(input.poll());
  serialPoll();

  if (scr == Scr::Mark && gps.markDone()) {
    GeoPoint p;
    if (gps.finishMark(p)) applyMark(p);
    else openMarkFailed();
  }
  if (scr == Scr::Result && now - resultAt > RESULT_SHOW_MS) go(Scr::Club);

  if (fuelOk && (now - lastFuel >= FUEL_POLL_MS || lastFuel == 0)) {
    lastFuel = now;
    batteryPct = constrain((int)lround(fuel.getSOC()), 0, 100);
    updateCharging(now, fuel.getVoltage(), fuel.getChangeRate());
  }

  if (dirty || now - lastRender >= UI_REFRESH_MS) {
    render();
    updateLed();
    dirty = false;
    lastRender = now;
  }
}

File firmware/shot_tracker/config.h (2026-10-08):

#pragma once
#include <Arduino.h>

// ---------------------------------------------------------------------------
// Hardware (SparkFun Thing Plus ESP32-S3, from SparkFun's KiCad netlist)
// ---------------------------------------------------------------------------
constexpr int PIN_QWIIC_EN = 45;  // drives the RT9080 that powers the Qwiic rail (GPS, OLED, Twist)
constexpr int PIN_SDA = 8;
constexpr int PIN_SCL = 9;
constexpr uint32_t I2C_HZ = 400000;

// ---------------------------------------------------------------------------
// Battery (MAX17048 fuel gauge)
// ---------------------------------------------------------------------------
constexpr uint32_t FUEL_POLL_MS = 1000;
// Plugging in steps the cell voltage up by charge current x internal resistance
// (typically 50-100 mV) and unplugging steps it back down. A jump this big
// against the recent baseline flips the charging icon immediately.
constexpr float CHG_STEP_V = 0.030f;
// With no step seen for CHG_SETTLE_MS, fall back to the gauge's charge rate
// (%/hr). It's heavily filtered, so it's only trusted once it has settled.
constexpr float CHG_RATE_ON = 1.0f;
constexpr float CHG_RATE_OFF = -1.0f;
constexpr uint32_t CHG_SETTLE_MS = 5UL * 60 * 1000;

// ---------------------------------------------------------------------------
// Round
// ---------------------------------------------------------------------------
constexpr uint8_t NUM_HOLES = 18;
constexpr uint16_t MAX_SHOTS = 250;  // per round; ~36 bytes each

// Club list shown on the dial. Order = dial order. Keep names <= 14 chars.
// The putter must be named exactly PUTTER_NAME (putts record one point, no landing).
#define PUTTER_NAME "Putter"
static const char* const CLUBS[] = {
    "Driver", "3 Wood", "5 Wood", "Hybrid", "4 Iron", "5 Iron", "6 Iron",
    "7 Iron", "8 Iron", "9 Iron", "PW",     "GW",     "SW",     "LW",
    PUTTER_NAME,
};
constexpr uint8_t NUM_CLUBS = sizeof(CLUBS) / sizeof(CLUBS[0]);
// The dial has one extra slot after the clubs: "Hole out" (finishes the hole).
constexpr uint8_t DIAL_HOLE_OUT = NUM_CLUBS;

// ---------------------------------------------------------------------------
// GPS
// ---------------------------------------------------------------------------
constexpr uint8_t GPS_NAV_HZ = 4;                 // solutions per second
constexpr uint32_t GPS_MARK_WINDOW_MS = 2500;     // average fixes for this long when marking a point
constexpr uint8_t GPS_MARK_MIN_SAMPLES = 3;       // below this the mark counts as failed
constexpr uint32_t GPS_MAX_GOOD_HACC_MM = 8000;   // fixes worse than this are ignored while marking

// ---------------------------------------------------------------------------
// UI
// ---------------------------------------------------------------------------
constexpr bool USE_YARDS = true;             // false = metres
constexpr uint32_t LONG_PRESS_MS = 700;      // hold the dial this long to open the menu
constexpr uint32_t RESULT_SHOW_MS = 4000;    // how long the "152 yds" result stays up
constexpr uint32_t UI_REFRESH_MS = 250;

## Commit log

2026-10-04 Initial commit: open-gps golf shot tracker v0.1
    ESP32-S3 Thing Plus firmware (single-dial UI, GPS-averaged shot marking,
    LittleFS round storage, GeoJSON/CSV export), host simulation, and a
    parametric OpenSCAD enclosure with printable STLs. Licensed AGPL-3.0.
    [knob.stl, lid.stl, plate.stl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]
2026-10-08 Fix charging icon lagging plug/unplug
    The icon came only from the MAX17048's charge rate, polled every 10 s. That
    estimate is heavily filtered, reads ~0 when plugged in near full, and the
    gauge hibernates (45 s sampling) whenever |rate| < ~27 %/hr. Keep the gauge
    awake while running (restore its default thresholds at power-off), poll every
    1 s, and detect plug/unplug from the cell-voltage step, falling back to the
    charge rate only once it has settled. Sim covers plug, unplug and lagging rate.
    [app.cpp, config.h, sim.cpp]
2026-10-08 Fix ~1 s GPS stalls that lagged the dial and dropped clicks
    The u-blox library occasionally misreads the module's bytes-available count
    as tens of thousands of bytes and reads them all: about a second at 400 kHz,
    during which nothing polls the dial or redraws, and the junk causes checksum
    errors. Measured on hardware: worst loop ~1000 ms every ~2 s. Wrap the I2C bus
    to clamp the count to 512 bytes (a real fix is ~100). Worst loop is now under
    30 ms at full bus speed and every tap registers.
2026-10-08 Case v0.1: room for a plug in the GPS's top-edge Qwiic port
    J4 sits beside the SMA, which pins the board 0.6 mm from the top wall, so the
    second GPS port (needed for the Thing Plus -> GPS -> OLED chain) couldn't take
    a plug. Add a pocket bulging out of the top wall behind J4 (5 mm from the board
    edge, 45-degree underside so it prints without supports) and move the zip-tie
    anchor to the other side of the SMA port. Re-export shell.stl.
    [shell.stl, shot_tracker_case.scad]
2026-10-08 Add round replay web viewer
    tools/replay/index.html loads a geojson or csv export on a satellite map and
    replays the round shot by shot with a scorecard and per-club stats. Works from
    file://. The built-in sample is synthetic (a real round moved, rotated and
    re-timed); personal exports in rounds/ are gitignored. Parser tests:
    node tools/replay/parse.test.mjs.
    [sample-round.csv]
2026-10-08 Add case concepts and print-ready Stone B2
    Concepts A (Grip) and B (Stone) with a shared TwistLock cart/strap mount, and
    B2, a layered Stone (63 x 75.5 x 32.6 mm without the mount socket). B2 has
    print-oriented STLs in case/concepts/stl_b2, fit checks for parts, screws and
    inserts, and a Printing B2 section with hardware, assembly and items to
    measure before printing.
    [back_shell.stl, concept_a_grip.scad, concept_b2_stone.scad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]
